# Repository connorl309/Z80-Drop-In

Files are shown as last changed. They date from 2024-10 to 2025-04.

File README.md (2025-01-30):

# Z80-Drop-In
Relevant links and information:
- [Instruction Set](https://map.grauw.nl/resources/z80instr.php)
- [Z80 User Manual](https://www.zilog.com/docs/z80/um0080.pdf)
- [Master Reference Website](http://z80.info/)
- [Timing Quirks](https://floooh.github.io/2021/12/06/z80-instruction-timing.html#extra-clock-cycles)

## Summary
This is the Github repository for the senior design capstone project class at the University of Texas at Austin's ECE program (ECE 364/464). Our group is Industry Honors 01 (IH01), a Drop-in CPU Replacement for the Zilog Z80 processor, comprised of six members:

1. [Connor Leu](https://github.com/connorl309) - Team lead, organizer, maintainer, PCB design
2. [April Douglas](https://github.com/MaprilBear) - ALU RTL, processor design
3. [Gage Miller](https://github.com/millergage) - Register file RTL, processor design
4. [Luke Mason](https://github.com/Mega567835) - Control store, microsequencer, FSM design
5. [Nadia Houston](https://github.com/nadiahouston) - Control store, microsequencer, FSM design
6. [Gabriel Moore](https://github.com/K0-p) - Hardware testing, development boards

This project is considered an industry-honors project; as such, we are sponsored and primarily funded by an industry company, [Phoenix Semiconductor](https://www.phoenixsemicorp.com/).

The premise behind our drop-in replacement is to create a cycle-accurate processor core emulator on an FPGA. For our project, under company guidance, we are targeting the Spartan-7 XC7S15. The emulated processor core will sit on a supporting custom PCB, sized to the original form factor (approx. 17mm x 50mm) of the Zilog Z80. This PCB will then assume the position of a Z80 in any Z80 system, mimicking original processor behavior accurately.

The two major components of this project is the processor design and the hardware design. Our processor emulation core is split into datapath design and a control store/microcode FSM. The three major components of the datapath are the ALU, register file, and control logic. The control store and microcode represent our implementation of the original Z80's PLA for instruction decode and processor operation. Our RTL design decisions have been informed by over 40 years of processor execution behavior, the original user manual, and countless online documents written by reverse engineers and hobbyists. (see [Master Reference Website](http://z80.info/))

The hardware design is also split into two primary components: the devhat translation boards, used to level-shift our development boards 3.3V signals to the Z80 5V level and vice versa, and the System-in-Package board, which is the final goal of the project. The SiP board features the Spartan-7 FPGA, control hardware, QSPI flash memory, and other supporting circuitry in the size of the original Z80 package. Our hope is that this final board will be a true drop-in replacement for Z80 processors.

The SiP board can be found in [hardware/sip-board](hardware/sip-board/), and the level shifter board can be found in [hardware/level-shifter/](hardware/level-shifter/). Component files are kind of messy, but both Kicad Projects should all be using RELATIVE paths for custom symbols and footprints.

## Tools
Given the nature of an FPGA-based processor emulator, we opted to use as many industry-standard tools as possible. Our RTL is written in Verilog under the Vivado Design Suite, targeting a Spartan-7 **XC7S15** FPGA for final project completion. We are hoping to acquire physical testing equipment to validate circuit boards. Our hardware is designed using KiCad, as the University does not provide licenses for software such as Altium or Allegro.

## Building and Testing
Vivado's IP for FPGAs has lots of different blocks we can use. One such IP block is the [integrated logic analyzer (ILA)](https://www.xilinx.com/products/intellectual-property/ila.html). Instead of needing more PCBs or fancy test rigs, we can utilize the ILA directly on our development FPGA boards and dump waveforms right back out to the host PC and into the Vivado Waveform viewer. This is our primary method of testing and verification on the development boards (purchased from Numato - the Narvi S7). In addition to the ILA, our devboards also contain FTDI chips that let us communicate over serial to the host computer.
Our goal for devboard testing is to be able to execute any number of sample programs for the Z80, and verify that all control signals are accurate to both the M- and T-cycle level. This will likely take the form of short sample programs for all instructions, and then combined into larger test programs with more complex behavior whose validity will be examined on a results level, not a cycle level.

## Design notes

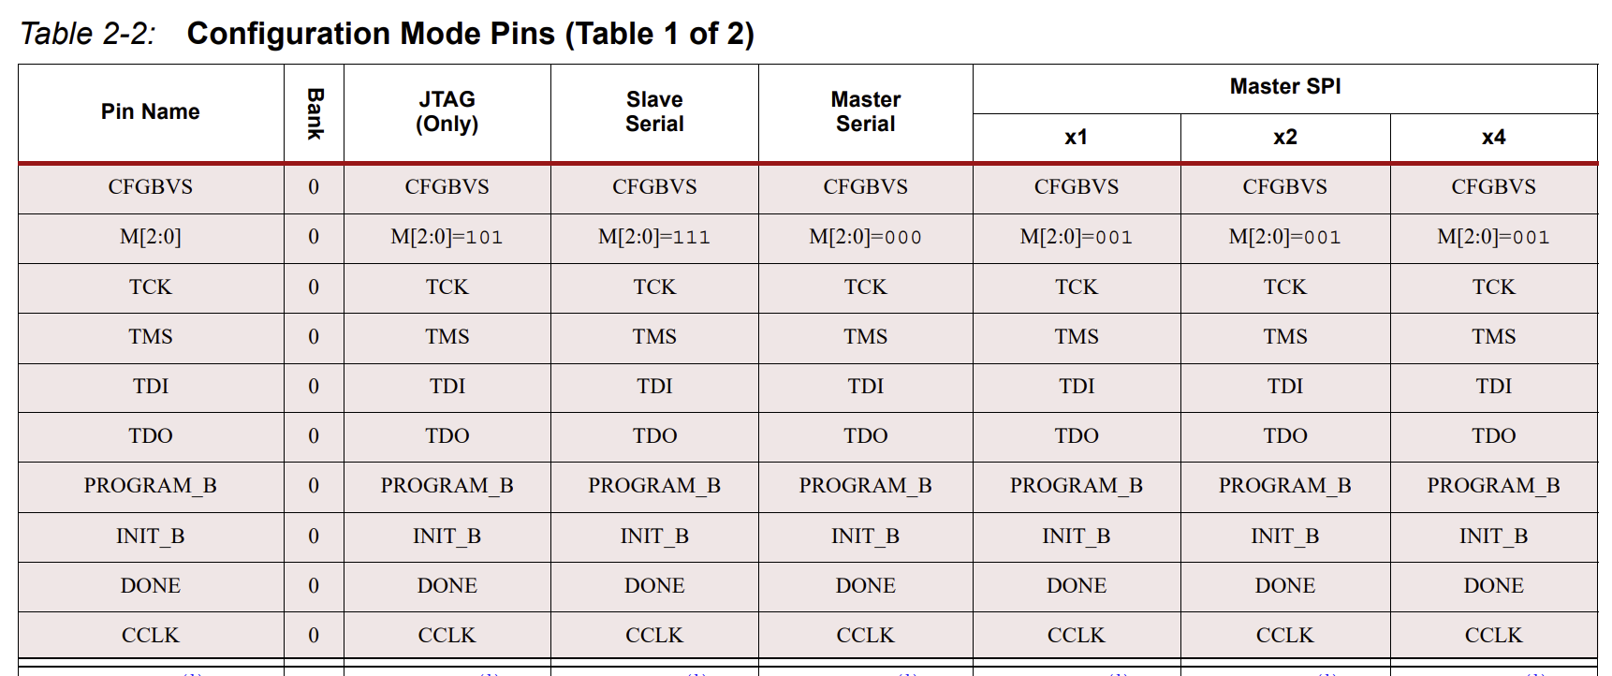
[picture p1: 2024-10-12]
hardware/xc7s15 configuration pin table.png

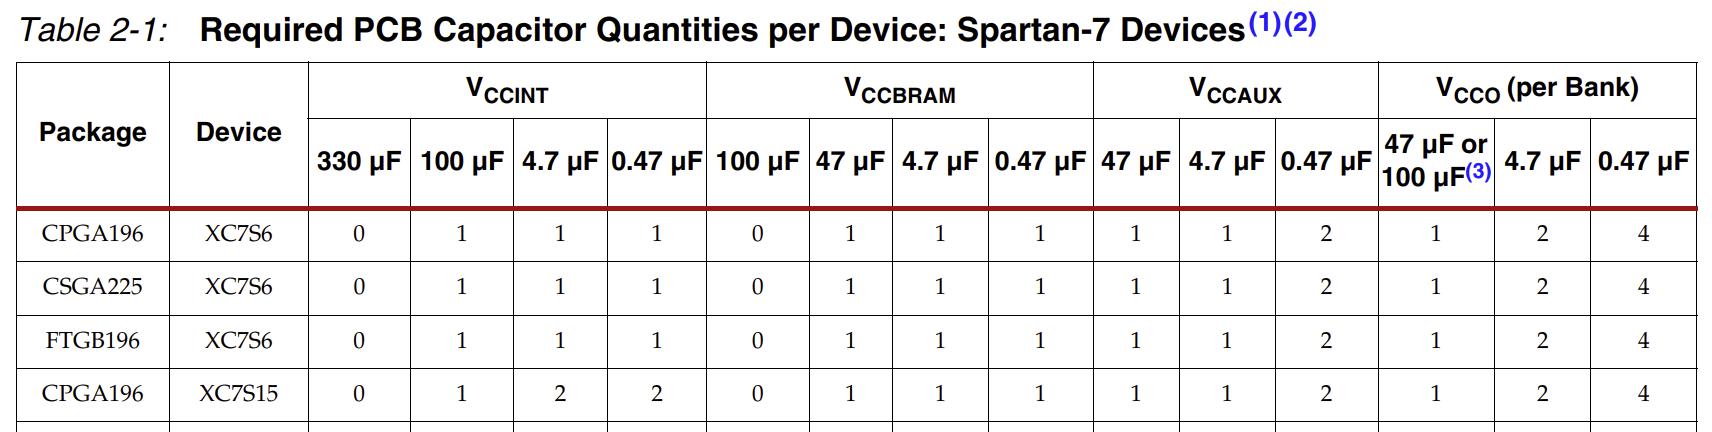
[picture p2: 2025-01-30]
hardware/decoupling caps.png

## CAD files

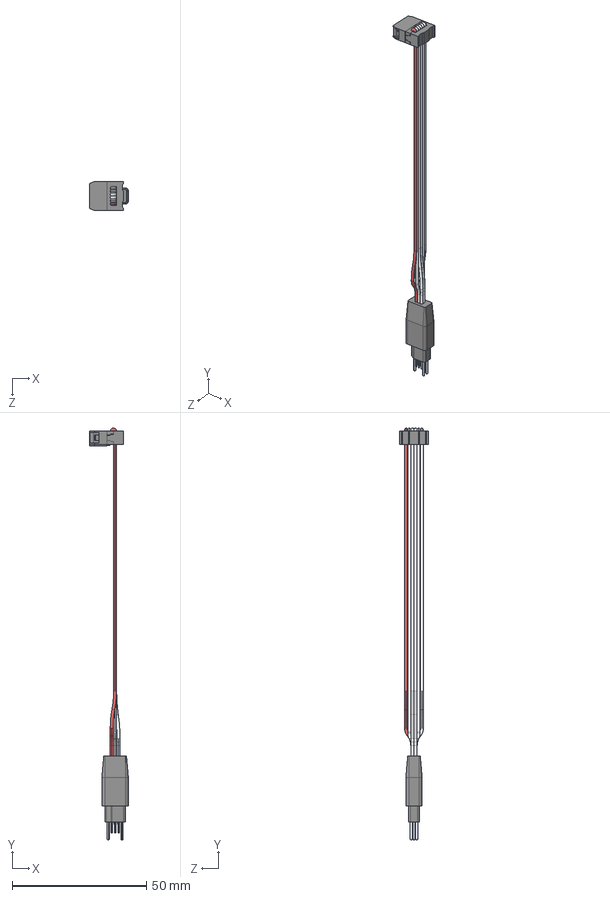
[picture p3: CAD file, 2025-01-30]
hardware/TC2030-IDC-NL.step
14.5 x 153.6 x 10.7 mm

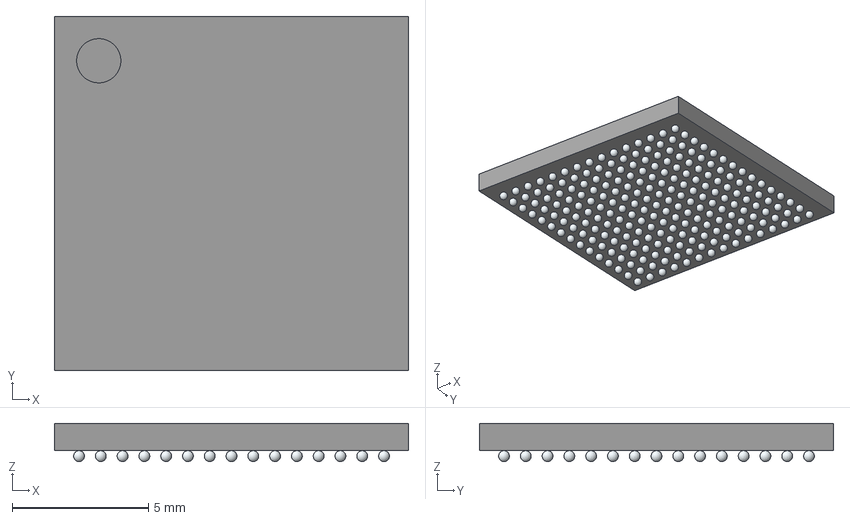
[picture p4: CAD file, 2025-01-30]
hardware/XC7S25-2CSGA225I.stp
13.0 x 13.0 x 1.40 mm

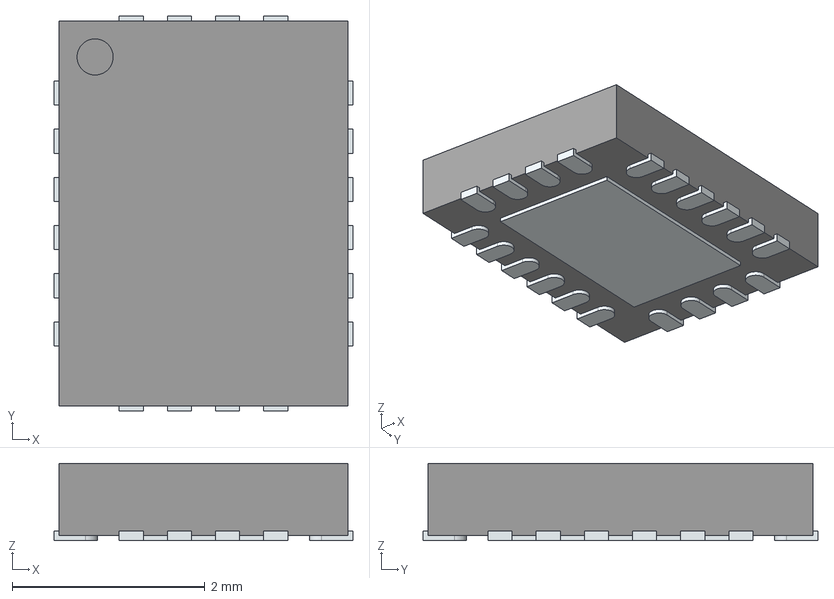
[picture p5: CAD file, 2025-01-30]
hardware/LTC3569EUDC#TRPBF.stp
3.10 x 4.10 x 0.8 mm
ThermalPin
PinsArrayLR
PinsArrayTB

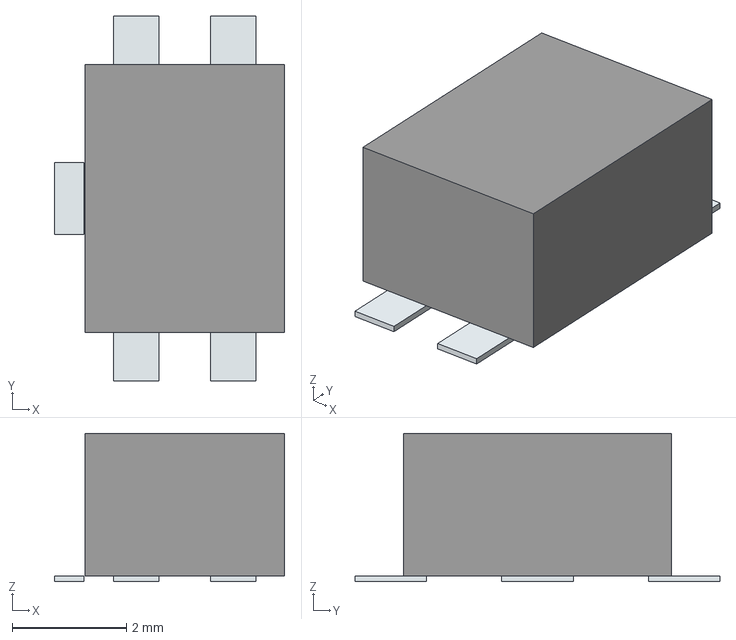
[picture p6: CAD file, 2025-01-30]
hardware/EVQ-P2R02W.stp
4.04 x 6.40 x 2.60 mm
Pins

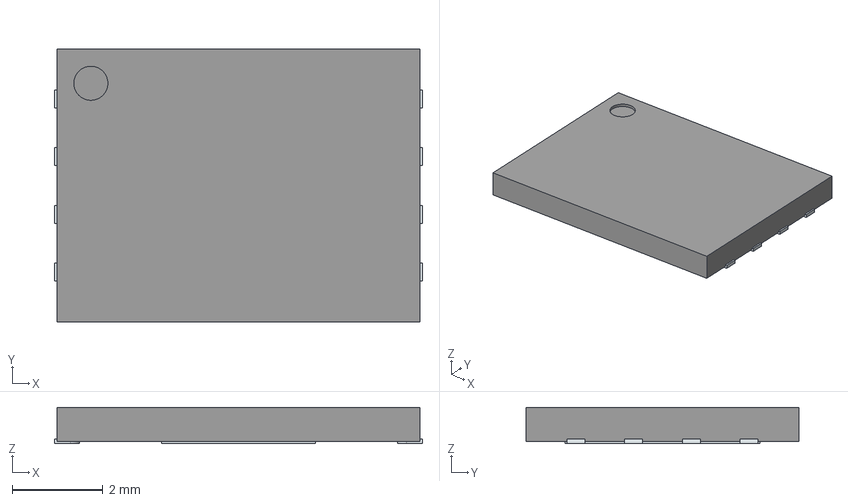
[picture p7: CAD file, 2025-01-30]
hardware/MT25QL512ABB1EW9-0SIT.stp
8.10 x 6.00 x 0.8 mm
ThermalPin
PinsArrayLR

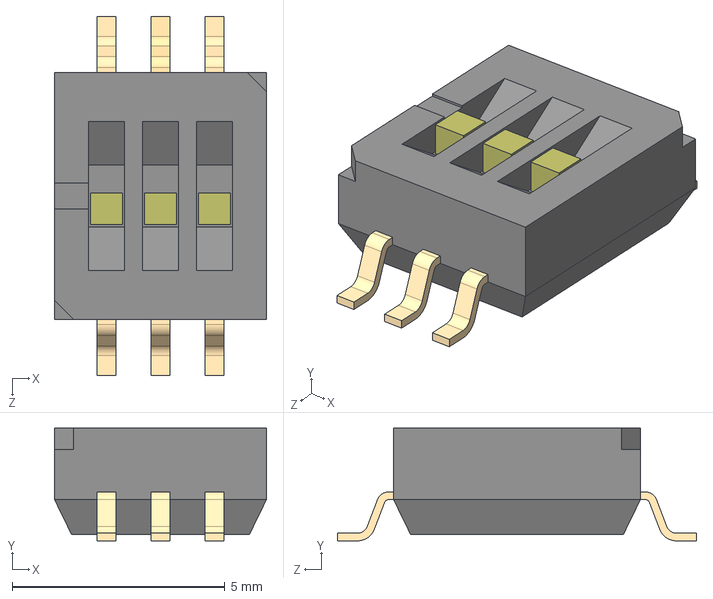
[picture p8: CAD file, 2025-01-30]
hardware/416131160803.stp
4.98 x 2.65 x 8.44 mm

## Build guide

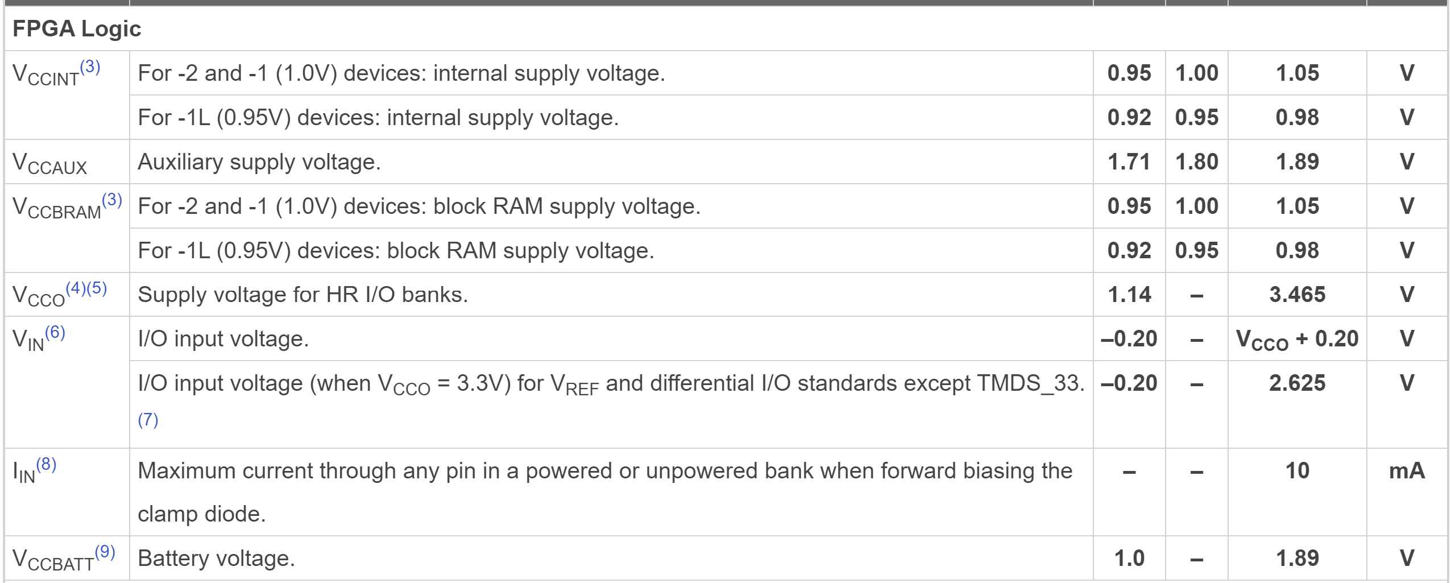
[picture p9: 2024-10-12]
hardware/xc7s15 operating power conditions.png

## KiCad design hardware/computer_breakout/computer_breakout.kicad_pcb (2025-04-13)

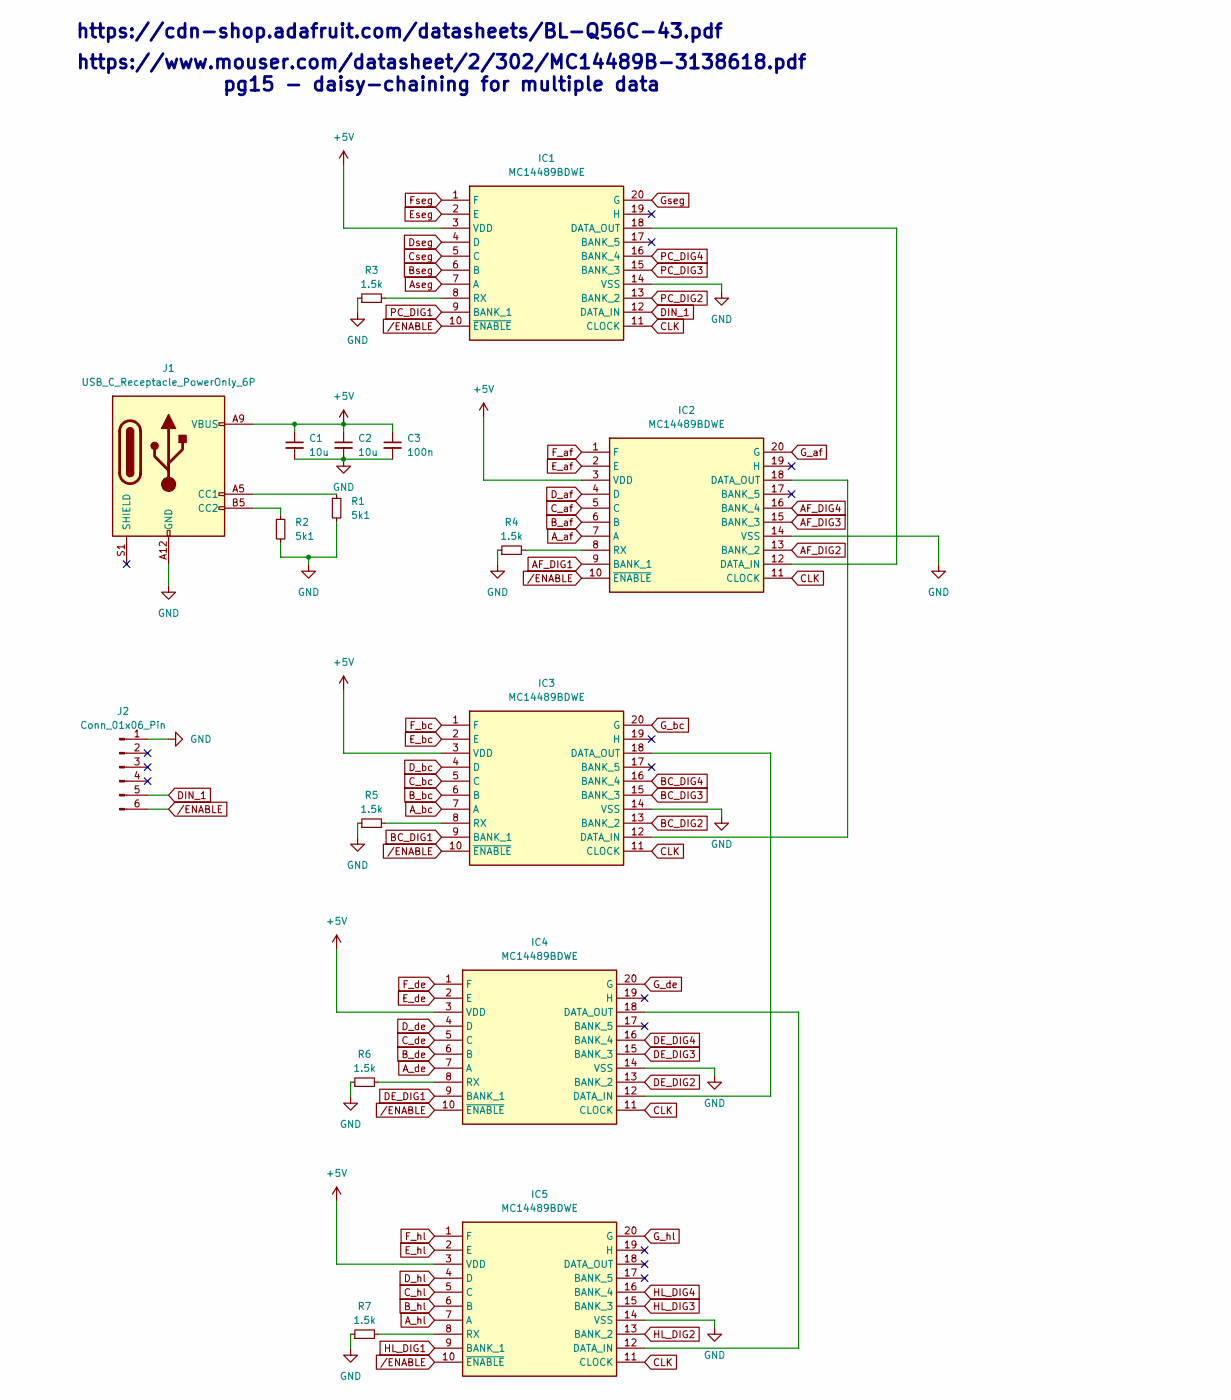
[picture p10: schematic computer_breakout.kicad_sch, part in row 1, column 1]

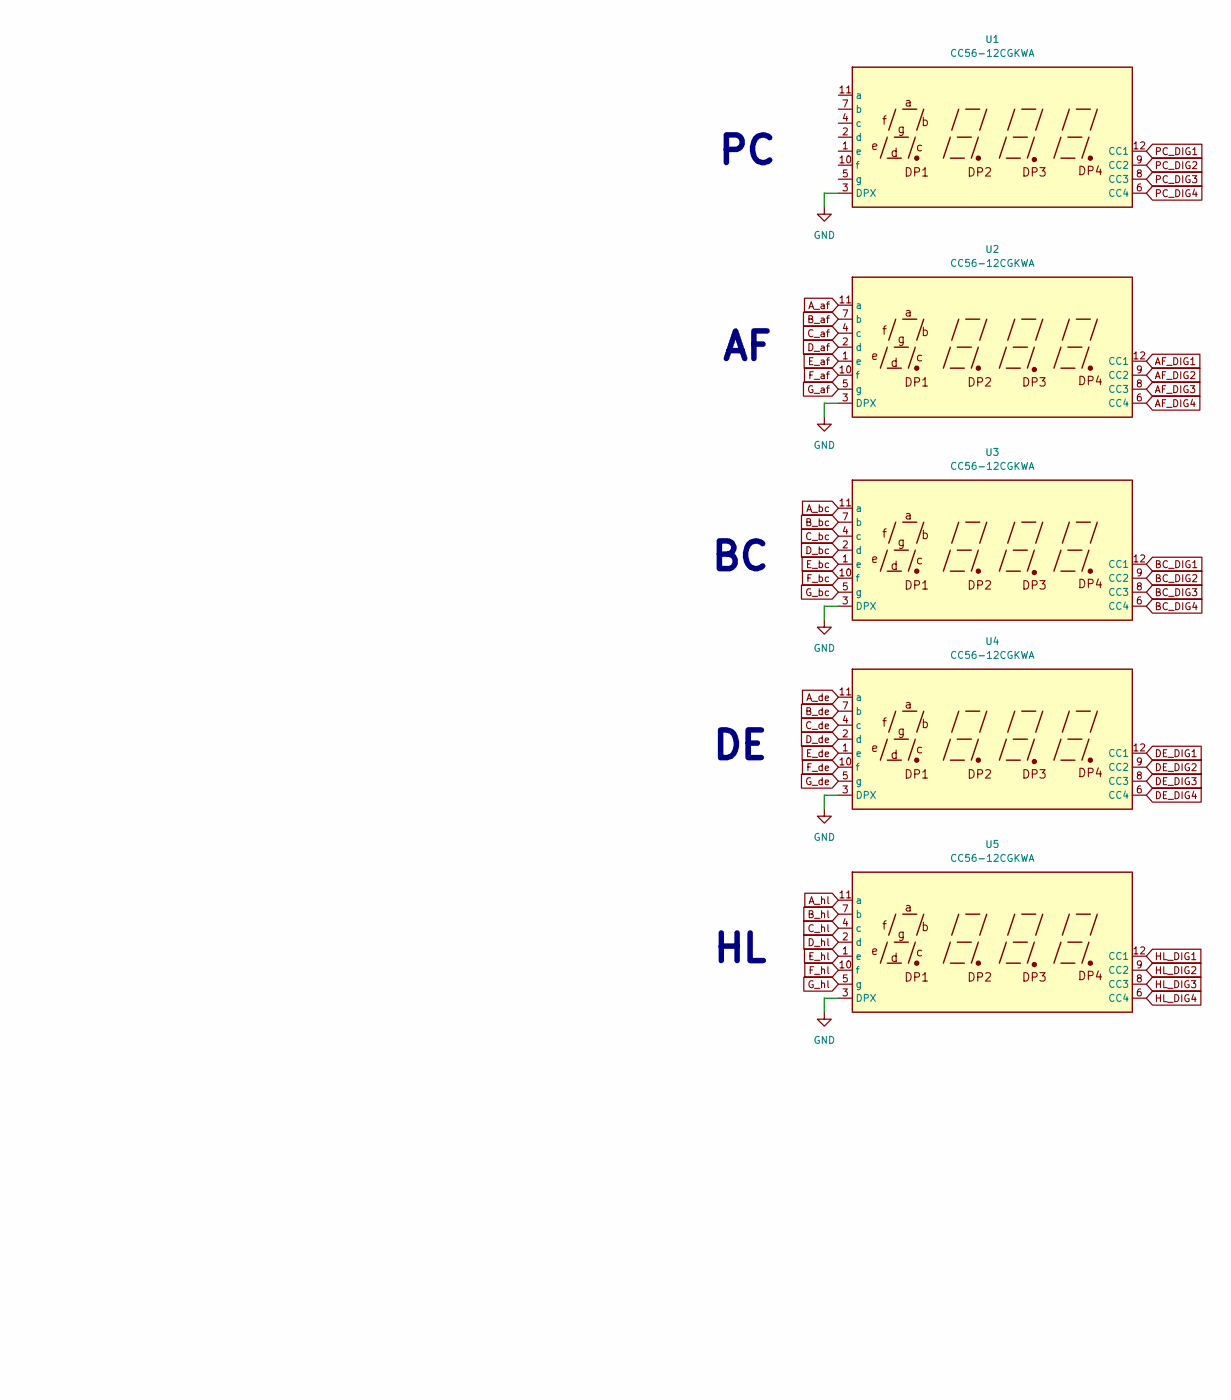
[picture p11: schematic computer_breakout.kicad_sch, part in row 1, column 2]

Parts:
C1, C2: 10u; C_1206_3216Metric_Pad1.33x1.80mm_HandSolder
C3: 100n; C_0603_1608Metric_Pad1.08x0.95mm_HandSolder
IC1, IC2, IC3, IC4, IC5: MC14489BDWE; SOIC127P1030X265-20N; Mouser Part Number 841-MC14489BDWE
J1: USB_C_Receptacle_PowerOnly_6P; USB_C_Receptacle_GCT_USB4110
J2: Conn_01x06_Pin; PinHeader_1x06_P2.54mm_Vertical
R1, R2: 5k1; R_1812_4532Metric_Pad1.30x3.40mm_HandSolder
R3, R4, R5, R6, R7: 1.5k; R_1812_4532Metric_Pad1.30x3.40mm_HandSolder
U1, U2, U3, U4, U5: CC56-12CGKWA; CA56-12CGKWA

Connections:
+5V: C1.1, C2.1, C3.1, IC1.3 (VDD), IC2.3 (VDD), IC3.3 (VDD), IC4.3 (VDD), IC5.3 (VDD), J1.A9 (VBUS), J1.B9 (VBUS)
AF_DIG1: IC2.9 (BANK_1), U2.12 (CC1)
AF_DIG2: IC2.13 (BANK_2), U2.9 (CC2)
AF_DIG3: IC2.15 (BANK_3), U2.8 (CC3)
AF_DIG4: IC2.16 (BANK_4), U2.6 (CC4)
A_af: IC2.7 (A), U2.11 (a)
A_bc: IC3.7 (A), U3.11 (a)
A_de: IC4.7 (A), U4.11 (a)
A_hl: IC5.7 (A), U5.11 (a)
Aseg: IC1.7 (A)
BC_DIG1: IC3.9 (BANK_1), U3.12 (CC1)
BC_DIG2: IC3.13 (BANK_2), U3.9 (CC2)
BC_DIG3: IC3.15 (BANK_3), U3.8 (CC3)
BC_DIG4: IC3.16 (BANK_4), U3.6 (CC4)
B_af: IC2.6 (B), U2.7 (b)
B_bc: IC3.6 (B), U3.7 (b)
B_de: IC4.6 (B), U4.7 (b)
B_hl: IC5.6 (B), U5.7 (b)
Bseg: IC1.6 (B)
CLK: IC1.11 (CLOCK), IC2.11 (CLOCK), IC3.11 (CLOCK), IC4.11 (CLOCK), IC5.11 (CLOCK)
C_af: IC2.5 (C), U2.4 (c)
C_bc: IC3.5 (C), U3.4 (c)
C_de: IC4.5 (C), U4.4 (c)
C_hl: IC5.5 (C), U5.4 (c)
Cseg: IC1.5 (C)
DE_DIG1: IC4.9 (BANK_1), U4.12 (CC1)
DE_DIG2: IC4.13 (BANK_2), U4.9 (CC2)
DE_DIG3: IC4.15 (BANK_3), U4.8 (CC3)
DE_DIG4: IC4.16 (BANK_4), U4.6 (CC4)
DIN_1: IC1.12 (DATA_IN), J2.5
D_af: IC2.4 (D), U2.2 (d)
D_bc: IC3.4 (D), U3.2 (d)
D_de: IC4.4 (D), U4.2 (d)
D_hl: IC5.4 (D), U5.2 (d)
Dseg: IC1.4 (D)
E_af: IC2.2 (E), U2.1 (e)
E_bc: IC3.2 (E), U3.1 (e)
E_de: IC4.2 (E), U4.1 (e)
E_hl: IC5.2 (E), U5.1 (e)
Eseg: IC1.2 (E)
F_af: IC2.1 (F), U2.10 (f)
F_bc: IC3.1 (F), U3.10 (f)
F_de: IC4.1 (F), U4.10 (f)
F_hl: IC5.1 (F), U5.10 (f)
Fseg: IC1.1 (F)
GND: C1.2, C2.2, C3.2, IC1.14 (VSS), IC2.14 (VSS), IC3.14 (VSS), IC4.14 (VSS), IC5.14 (VSS), J1.A12 (GND), J1.B12 (GND), J2.1, R1.2, R2.2, R3.1, R4.1, R5.1, R6.1, R7.1, U1.3 (DPX), U2.3 (DPX), U3.3 (DPX), U4.3 (DPX), U5.3 (DPX)
G_af: IC2.20 (G), U2.5 (g)
G_bc: IC3.20 (G), U3.5 (g)
G_de: IC4.20 (G), U4.5 (g)
G_hl: IC5.20 (G), U5.5 (g)
Gseg: IC1.20 (G)
HL_DIG1: IC5.9 (BANK_1), U5.12 (CC1)
HL_DIG2: IC5.13 (BANK_2), U5.9 (CC2)
HL_DIG3: IC5.15 (BANK_3), U5.8 (CC3)
HL_DIG4: IC5.16 (BANK_4), U5.6 (CC4)
unnamed: IC1.18 (DATA_OUT), IC2.12 (DATA_IN)
unnamed: IC1.8 (RX), R3.2
unnamed: IC2.18 (DATA_OUT), IC3.12 (DATA_IN)
unnamed: IC2.8 (RX), R4.2
unnamed: IC3.18 (DATA_OUT), IC4.12 (DATA_IN)
unnamed: IC3.8 (RX), R5.2
unnamed: IC4.18 (DATA_OUT), IC5.12 (DATA_IN)
unnamed: IC4.8 (RX), R6.2
unnamed: IC5.8 (RX), R7.2
unnamed: J1.A5 (CC1), R1.1
unnamed: J1.B5 (CC2), R2.1
PC_DIG1: IC1.9 (BANK_1), U1.12 (CC1)
PC_DIG2: IC1.13 (BANK_2), U1.9 (CC2)
PC_DIG3: IC1.15 (BANK_3), U1.8 (CC3)
PC_DIG4: IC1.16 (BANK_4), U1.6 (CC4)
/ENABLE: IC1.10 (~ENABLE), IC2.10 (~ENABLE), IC3.10 (~ENABLE), IC4.10 (~ENABLE), IC5.10 (~ENABLE), J2.6

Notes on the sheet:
https://www.mouser.com/datasheet/2/302/MC14489B-3138618.pdf pg15 - daisy-chaining for multiple data
https://cdn-shop.adafruit.com/datasheets/BL-Q56C-43.pdf

Board: 2 copper layers, 22 parts (0 on the bottom side), 64 nets, no tracks yet.

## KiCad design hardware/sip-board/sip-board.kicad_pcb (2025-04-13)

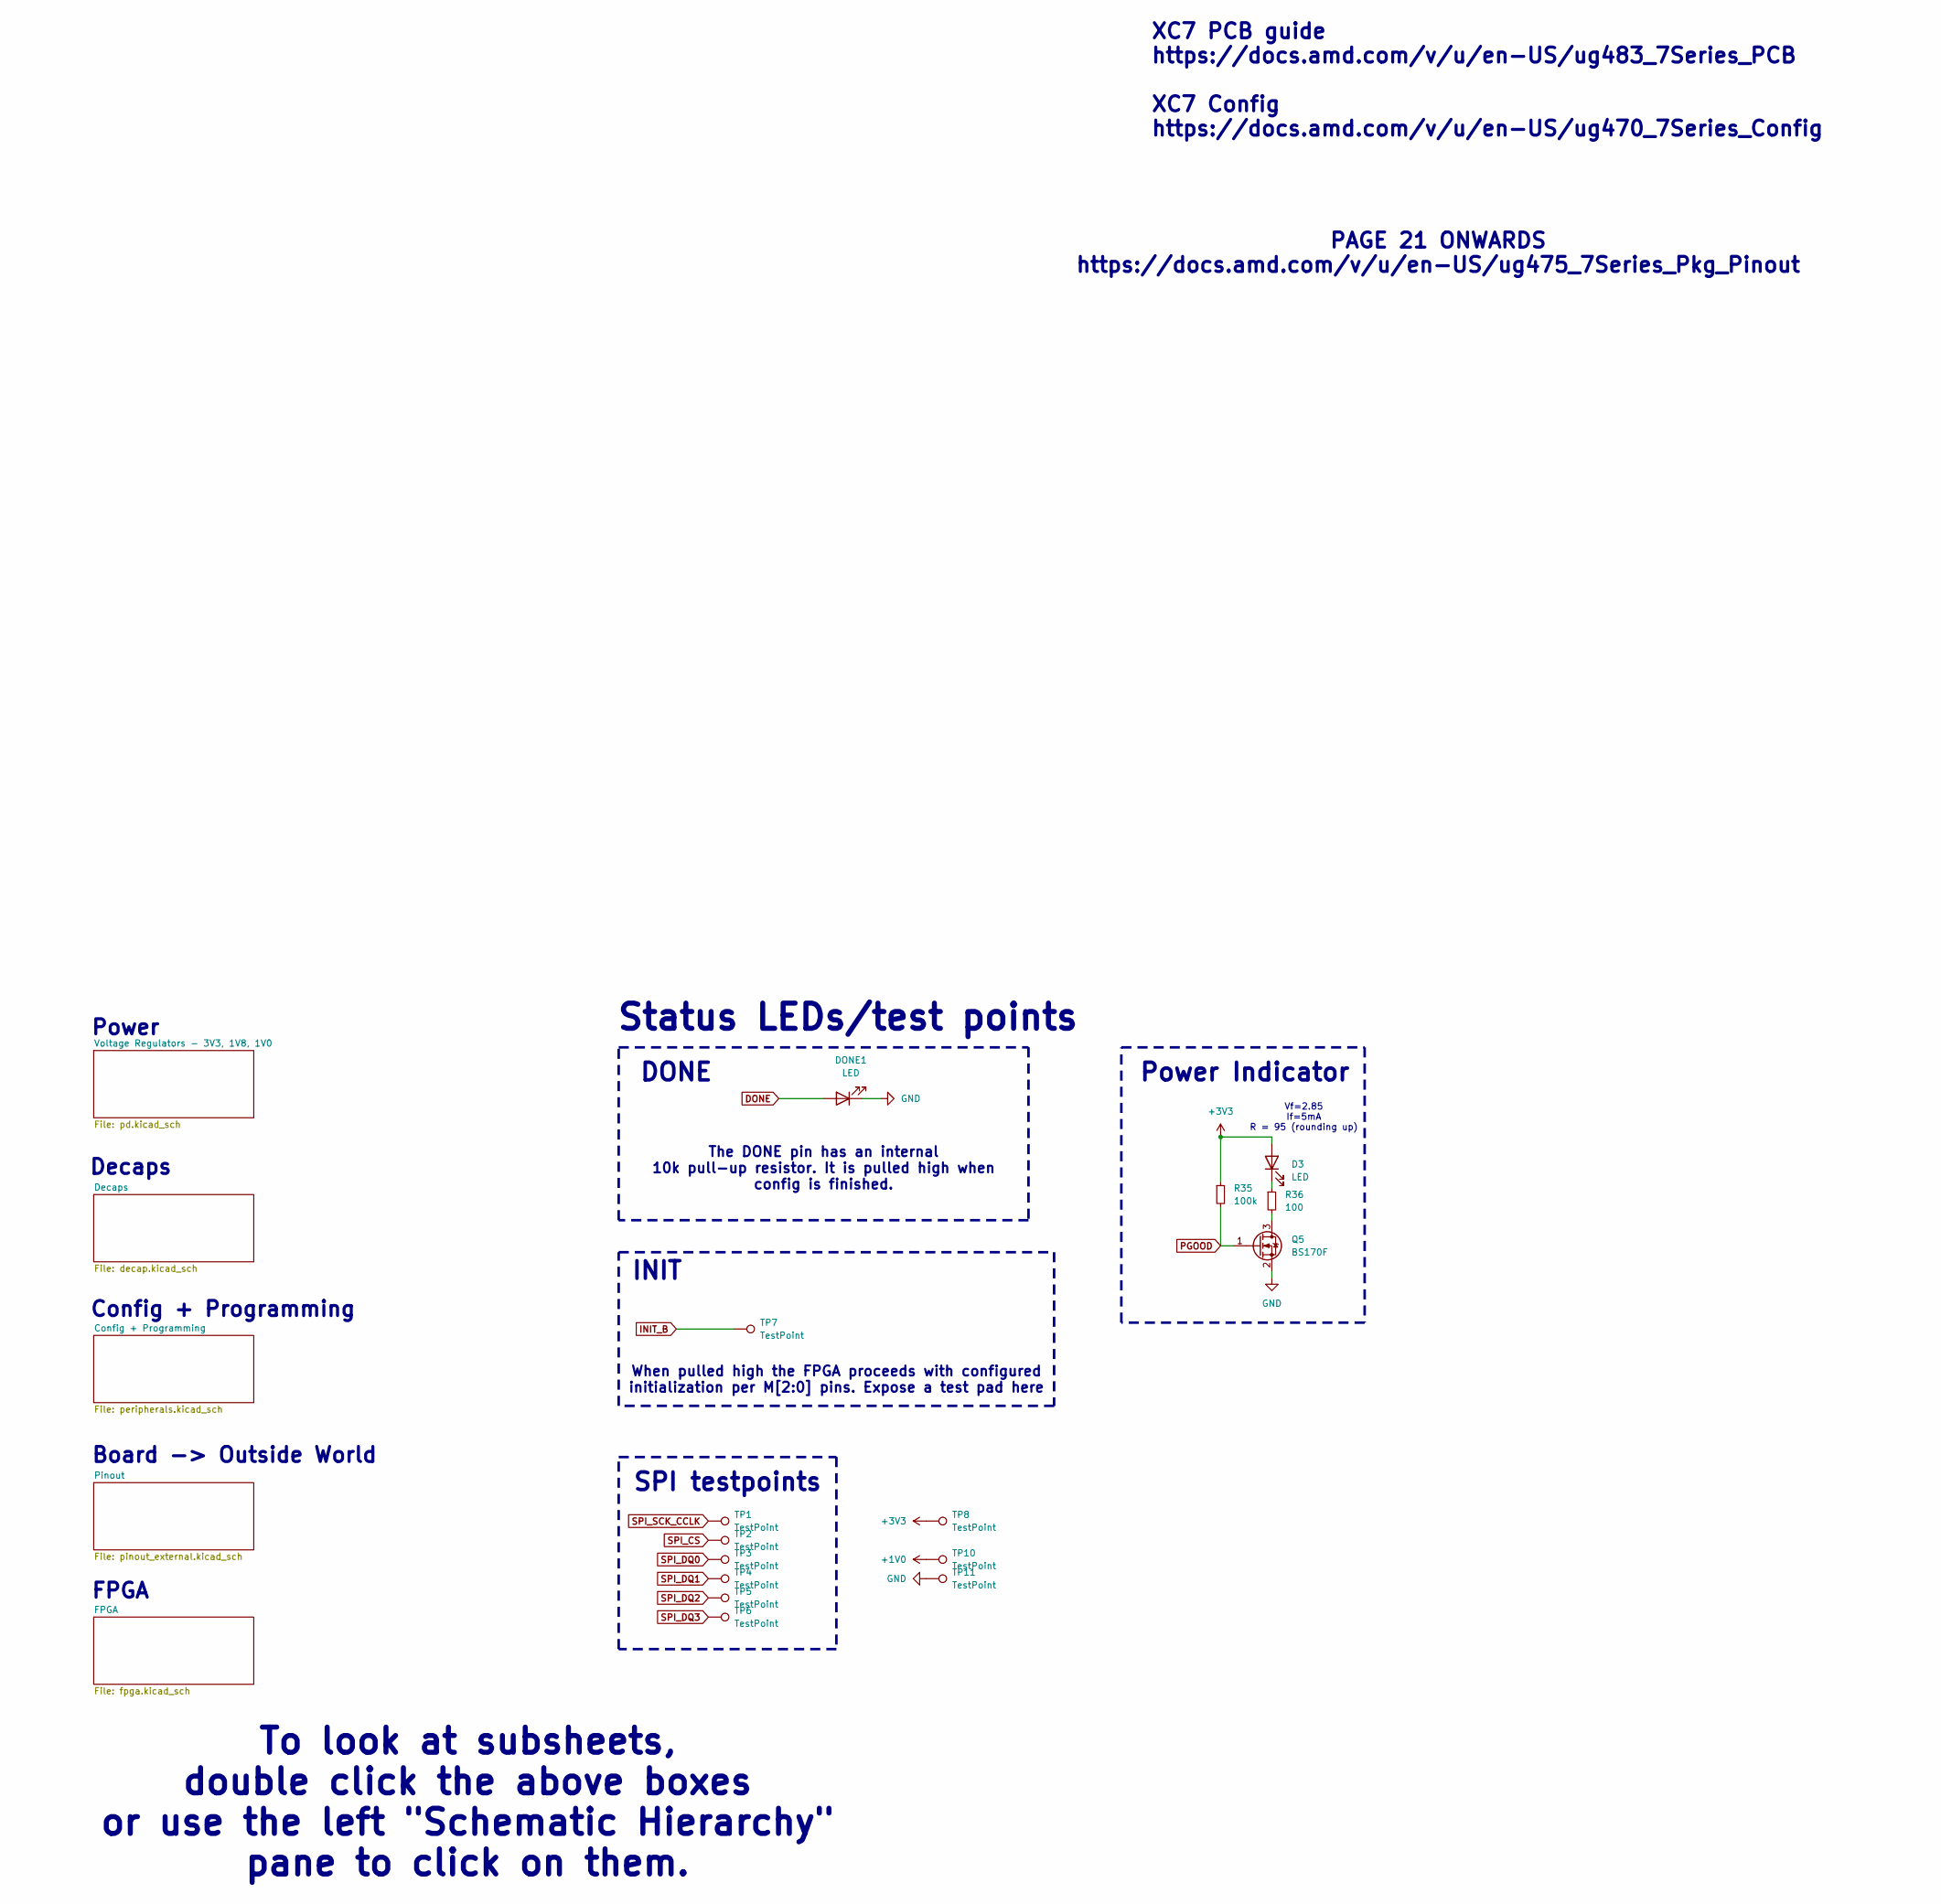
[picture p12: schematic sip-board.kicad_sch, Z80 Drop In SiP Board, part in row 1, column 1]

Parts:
D3: LED; LED_0402_1005Metric
DONE1: LED; LED_0402_1005Metric
Q5: BS170F; SOT-23
R35: 100k; R_0201_0603Metric
R36: 100; R_0201_0603Metric
TP1, TP2, TP3, TP4, TP5, TP6, TP7, TP8, TP10, TP11: TestPoint; TestPoint_Pad_1.0x1.0mm

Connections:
+1V0: TP10.1; also elsewhere on the board
+3V3: D3.2 (A), R35.1, TP8.1; also elsewhere on the board
DONE: DONE1.2 (A); also elsewhere on the board
GND: DONE1.1 (K), Q5.2 (S), TP11.1; also elsewhere on the board
INIT_B: TP7.1; also elsewhere on the board
unnamed: D3.1 (K), R36.1
unnamed: Q5.3 (D), R36.2
PGOOD: Q5.1 (G), R35.2; also elsewhere on the board
SPI_CS: TP2.1; also elsewhere on the board
SPI_DQ0: TP3.1; also elsewhere on the board
SPI_DQ1: TP4.1; also elsewhere on the board
SPI_DQ2: TP5.1; also elsewhere on the board
SPI_DQ3: TP6.1; also elsewhere on the board
SPI_SCK_CCLK: TP1.1; also elsewhere on the board

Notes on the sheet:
Power
Status LEDs/test points
FPGA
Decaps
XC7 PCB guide https://docs.amd.com/v/u/en-US/ug483_7Series_PCB XC7 Config https://docs.amd.com/v/u/en-US/ug470_7Series_Config
Board -> Outside World
Power Indicator
PAGE 21 ONWARDS https://docs.amd.com/v/u/en-US/ug475_7Series_Pkg_Pinout
INIT
Config + Programming
https://docs.amd.com/r/en-US/ug1099-bga-device-design-rules/Power-Delivery-to-the-FPGA
When pulled high the FPGA proceeds with configured initialization per M[2:0] pins. Expose a test pad here
DONE
The DONE pin has an internal 10k pull-up resistor. It is pulled high when config is finished.
SPI testpoints
To look at subsheets, double click the above boxes or use the left "Schematic Hierarchy" pane to click on them.
Vf=2.85 If=5mA R = 95 (rounding up)

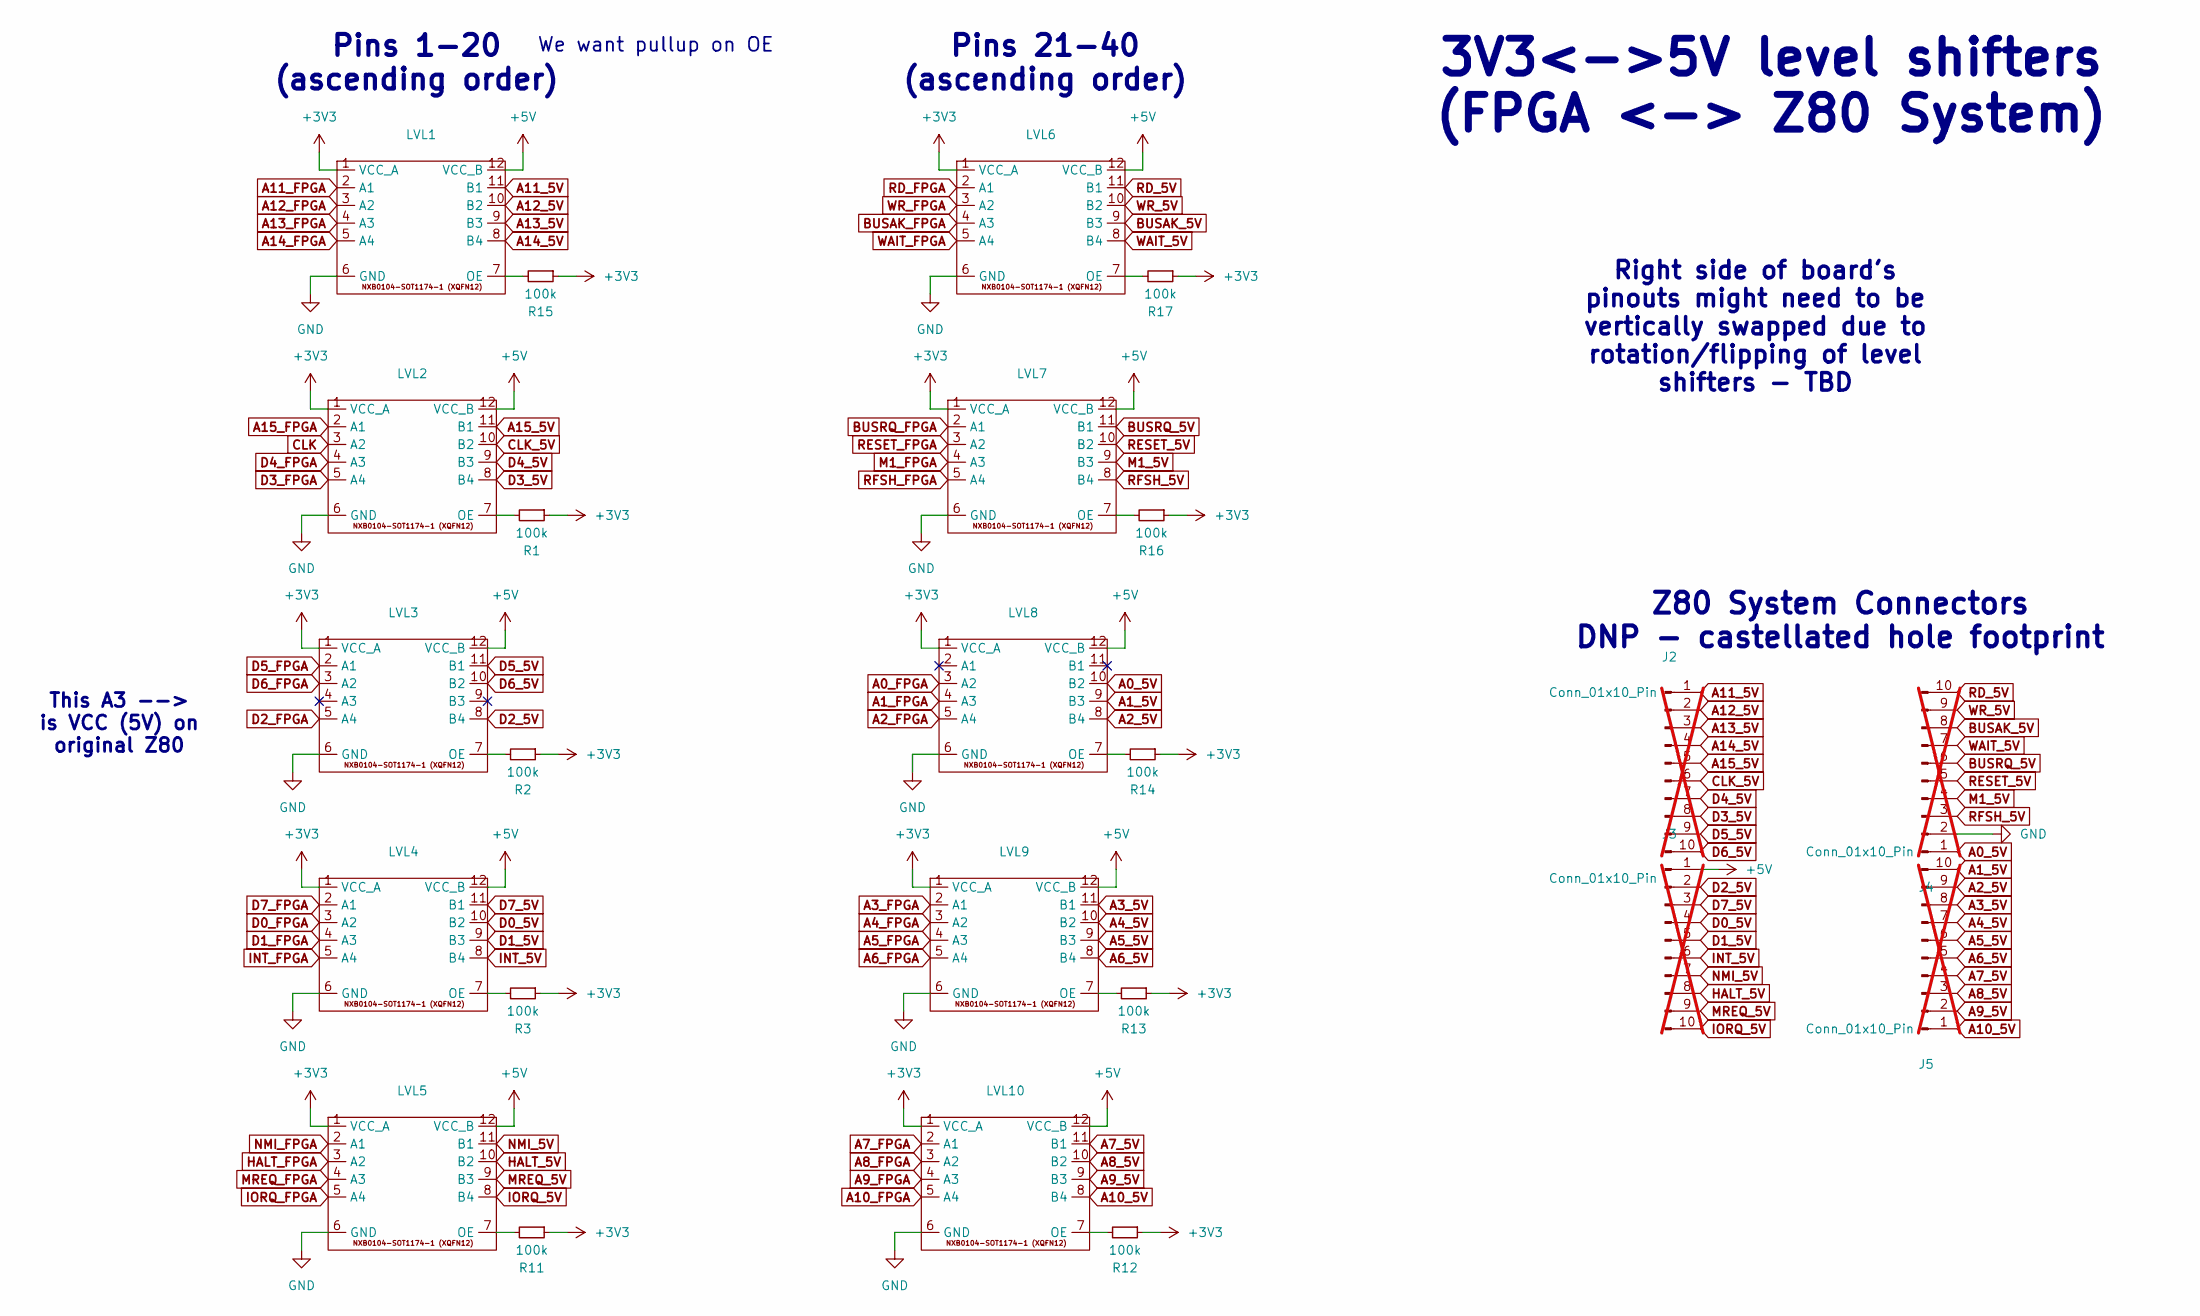
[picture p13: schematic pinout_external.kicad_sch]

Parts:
J2, J3, J4, J5: Conn_01x10_Pin; PinHeader_1x10_P2.54mm_Vertical; not fitted
LVL1, LVL2, LVL3, LVL4, LVL5, LVL6, LVL7, LVL8, LVL9, LVL10: NXB0104GU12X; MPN NXB0104GU12X
R1, R2, R3, R11, R12, R13, R14, R15, R16, R17: 100k; R_0201_0603Metric

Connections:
+3V3: LVL1.1 (VCC_A), LVL2.1 (VCC_A), LVL3.1 (VCC_A), LVL4.1 (VCC_A), LVL5.1 (VCC_A), LVL6.1 (VCC_A), LVL7.1 (VCC_A), LVL8.1 (VCC_A), LVL9.1 (VCC_A), LVL10.1 (VCC_A), R1.1, R2.1, R3.1, R11.1, R12.1, R13.1, R14.1, R15.1, R16.1, R17.1; also elsewhere on the board
+5V: J3.1, LVL1.12 (VCC_B), LVL2.12 (VCC_B), LVL3.12 (VCC_B), LVL4.12 (VCC_B), LVL5.12 (VCC_B), LVL6.12 (VCC_B), LVL7.12 (VCC_B), LVL8.12 (VCC_B), LVL9.12 (VCC_B), LVL10.12 (VCC_B); also elsewhere on the board
A0_5V: J4.1, LVL8.10 (B2)
A0_FPGA: LVL8.3 (A2); also elsewhere on the board
A1_5V: J5.10, LVL8.9 (B3)
A1_FPGA: LVL8.4 (A3); also elsewhere on the board
A2_5V: J5.9, LVL8.8 (B4)
A2_FPGA: LVL8.5 (A4); also elsewhere on the board
A3_5V: J5.8, LVL9.11 (B1)
A3_FPGA: LVL9.2 (A1); also elsewhere on the board
A4_5V: J5.7, LVL9.10 (B2)
A4_FPGA: LVL9.3 (A2); also elsewhere on the board
A5_5V: J5.6, LVL9.9 (B3)
A5_FPGA: LVL9.4 (A3); also elsewhere on the board
A6_5V: J5.5, LVL9.8 (B4)
A6_FPGA: LVL9.5 (A4); also elsewhere on the board
A7_5V: J5.4, LVL10.11 (B1)
A7_FPGA: LVL10.2 (A1); also elsewhere on the board
A8_5V: J5.3, LVL10.10 (B2)
A8_FPGA: LVL10.3 (A2); also elsewhere on the board
A9_5V: J5.2, LVL10.9 (B3)
A9_FPGA: LVL10.4 (A3); also elsewhere on the board
A10_5V: J5.1, LVL10.8 (B4)
A10_FPGA: LVL10.5 (A4); also elsewhere on the board
A11_5V: J2.1, LVL1.11 (B1)
A11_FPGA: LVL1.2 (A1); also elsewhere on the board
A12_5V: J2.2, LVL1.10 (B2)
A12_FPGA: LVL1.3 (A2); also elsewhere on the board
A13_5V: J2.3, LVL1.9 (B3)
A13_FPGA: LVL1.4 (A3); also elsewhere on the board
A14_5V: J2.4, LVL1.8 (B4)
A14_FPGA: LVL1.5 (A4); also elsewhere on the board
A15_5V: J2.5, LVL2.11 (B1)
A15_FPGA: LVL2.2 (A1); also elsewhere on the board
BUSAK_5V: J4.8, LVL6.9 (B3)
BUSAK_FPGA: LVL6.4 (A3); also elsewhere on the board
BUSRQ_5V: J4.6, LVL7.11 (B1)
BUSRQ_FPGA: LVL7.2 (A1); also elsewhere on the board
CLK: LVL2.3 (A2); also elsewhere on the board
CLK_5V: J2.6, LVL2.10 (B2)
D0_5V: J3.4, LVL4.10 (B2)
D0_FPGA: LVL4.3 (A2); also elsewhere on the board
D1_5V: J3.5, LVL4.9 (B3)
D1_FPGA: LVL4.4 (A3); also elsewhere on the board
D2_5V: J3.2, LVL3.8 (B4)
D2_FPGA: LVL3.5 (A4); also elsewhere on the board
D3_5V: J2.8, LVL2.8 (B4)
D3_FPGA: LVL2.5 (A4); also elsewhere on the board
D4_5V: J2.7, LVL2.9 (B3)
D4_FPGA: LVL2.4 (A3); also elsewhere on the board
D5_5V: J2.9, LVL3.11 (B1)
D5_FPGA: LVL3.2 (A1); also elsewhere on the board
D6_5V: J2.10, LVL3.10 (B2)
D6_FPGA: LVL3.3 (A2); also elsewhere on the board
D7_5V: J3.3, LVL4.11 (B1)
D7_FPGA: LVL4.2 (A1); also elsewhere on the board
GND: J4.2, LVL1.6 (GND), LVL2.6 (GND), LVL3.6 (GND), LVL4.6 (GND), LVL5.6 (GND), LVL6.6 (GND), LVL7.6 (GND), LVL8.6 (GND), LVL9.6 (GND), LVL10.6 (GND); also elsewhere on the board
HALT_5V: J3.8, LVL5.10 (B2)
HALT_FPGA: LVL5.3 (A2); also elsewhere on the board
INT_5V: J3.6, LVL4.8 (B4)
INT_FPGA: LVL4.5 (A4); also elsewhere on the board
IORQ_5V: J3.10, LVL5.8 (B4)
IORQ_FPGA: LVL5.5 (A4); also elsewhere on the board
M1_5V: J4.4, LVL7.9 (B3)
M1_FPGA: LVL7.4 (A3); also elsewhere on the board
MREQ_5V: J3.9, LVL5.9 (B3)
MREQ_FPGA: LVL5.4 (A3); also elsewhere on the board
NMI_5V: J3.7, LVL5.11 (B1)
NMI_FPGA: LVL5.2 (A1); also elsewhere on the board
unnamed: LVL1.7 (OE), R15.2
unnamed: LVL2.7 (OE), R1.2
unnamed: LVL3.7 (OE), R2.2
unnamed: LVL4.7 (OE), R3.2
unnamed: LVL5.7 (OE), R11.2
unnamed: LVL6.7 (OE), R17.2
unnamed: LVL7.7 (OE), R16.2
unnamed: LVL8.7 (OE), R14.2
unnamed: LVL9.7 (OE), R13.2
unnamed: LVL10.7 (OE), R12.2
RD_5V: J4.10, LVL6.11 (B1)
RD_FPGA: LVL6.2 (A1); also elsewhere on the board
RESET_5V: J4.5, LVL7.10 (B2)
RESET_FPGA: LVL7.3 (A2); also elsewhere on the board
RFSH_5V: J4.3, LVL7.8 (B4)
RFSH_FPGA: LVL7.5 (A4); also elsewhere on the board
WAIT_5V: J4.7, LVL6.8 (B4)
WAIT_FPGA: LVL6.5 (A4); also elsewhere on the board
WR_5V: J4.9, LVL6.10 (B2)
WR_FPGA: LVL6.3 (A2); also elsewhere on the board

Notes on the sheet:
3V3<->5V level shifters (FPGA <-> Z80 System)
Z80 System Connectors DNP - castellated hole footprint
This A3 --> is VCC (5V) on original Z80
We want pullup on OE
Right side of board's pinouts might need to be vertically swapped due to rotation/flipping of level shifters - TBD
Pins 21-40 (ascending order)
Pins 1-20 (ascending order)

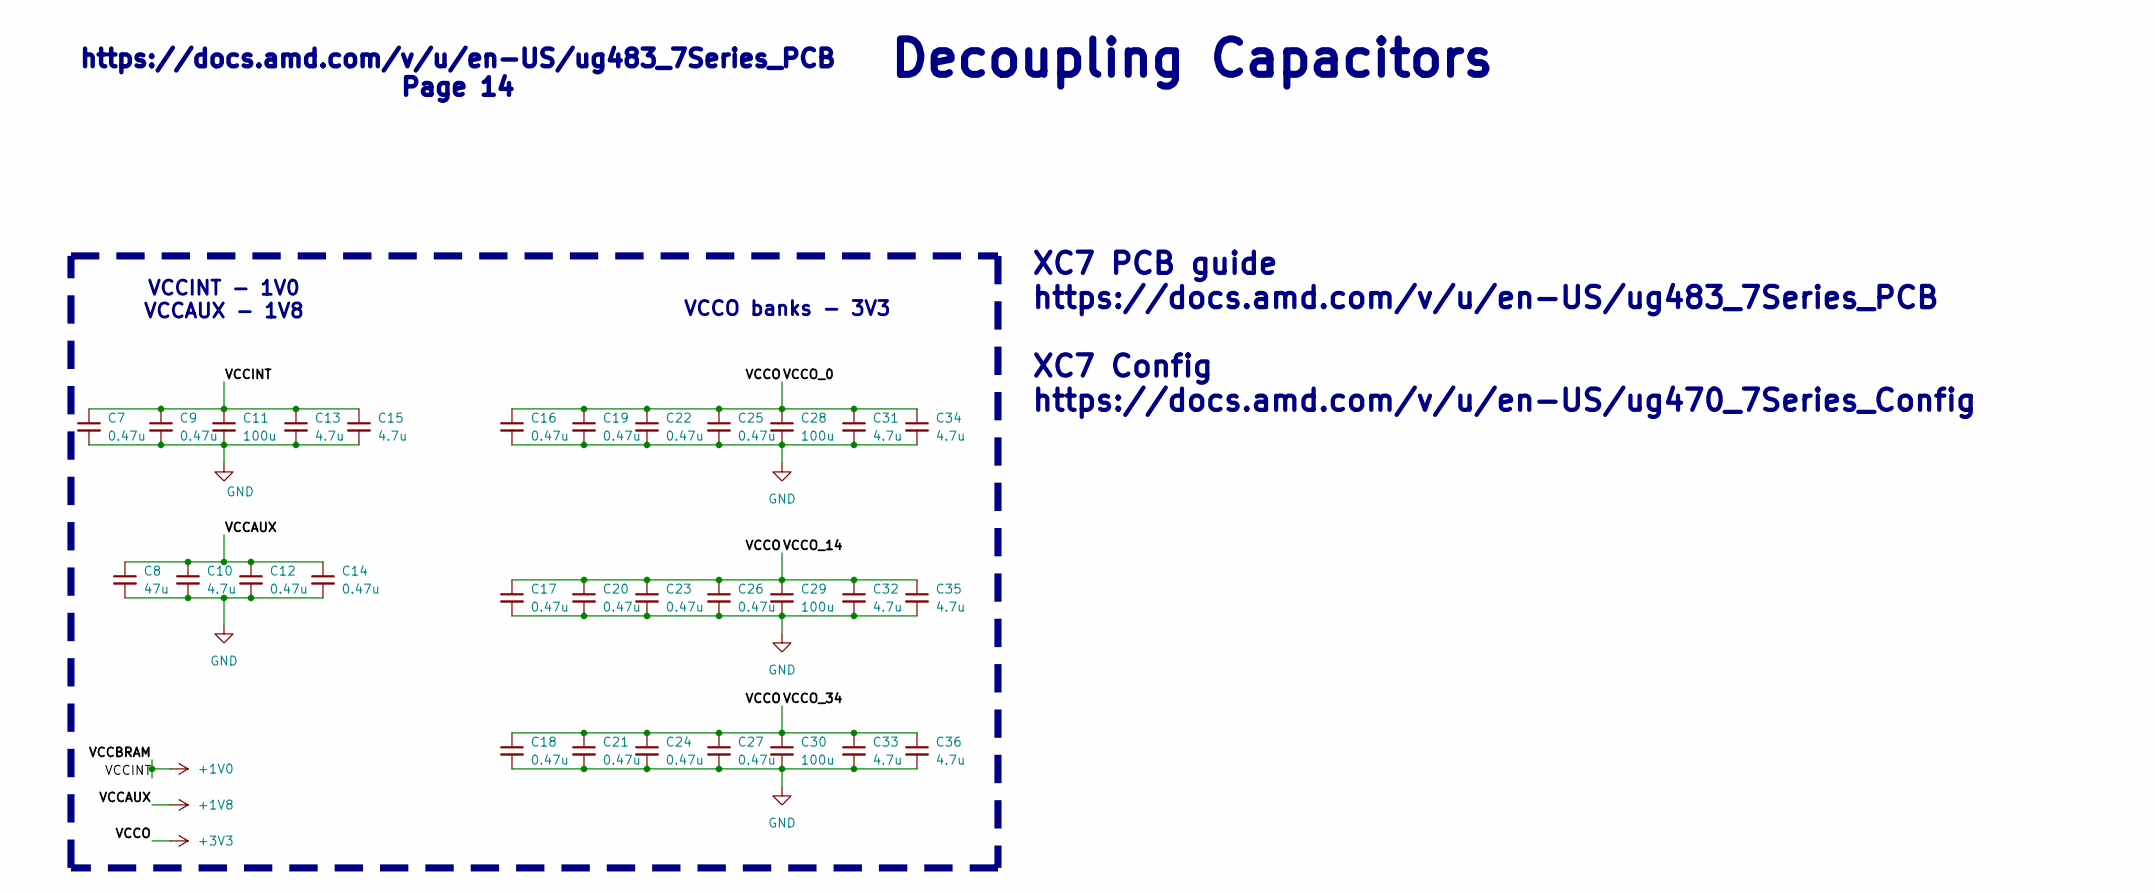
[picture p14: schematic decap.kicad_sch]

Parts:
C7, C9, C12, C14, C16, C17, C18, C19, C20, C21, C22, C23, C24, C25, C26, C27: 0.47u; C_0201_0603Metric
C8: 47u; C_0603_1608Metric
C10, C13, C15, C31, C32, C33, C34, C35, C36: 4.7u; C_0402_1005Metric
C11, C28, C29, C30: 100u; C_0603_1608Metric

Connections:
+1V0: C7.1, C9.1, C11.1, C13.1, C15.1; also elsewhere on the board
+1V8: C8.1, C10.1, C12.1, C14.1; also elsewhere on the board
+3V3: C16.1, C17.1, C18.1, C19.1, C20.1, C21.1, C22.1, C23.1, C24.1, C25.1, C26.1, C27.1, C28.1, C29.1, C30.1, C31.1, C32.1, C33.1, C34.1, C35.1, C36.1; also elsewhere on the board
GND: C7.2, C8.2, C9.2, C10.2, C11.2, C12.2, C13.2, C14.2, C15.2, C16.2, C17.2, C18.2, C19.2, C20.2, C21.2, C22.2, C23.2, C24.2, C25.2, C26.2, C27.2, C28.2, C29.2, C30.2, C31.2, C32.2, C33.2, C34.2, C35.2, C36.2; also elsewhere on the board

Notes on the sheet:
Decoupling Capacitors
XC7 PCB guide https://docs.amd.com/v/u/en-US/ug483_7Series_PCB XC7 Config https://docs.amd.com/v/u/en-US/ug470_7Series_Config
VCCO banks - 3V3
https://docs.amd.com/v/u/en-US/ug483_7Series_PCB Page 14
VCCINT - 1V0 VCCAUX - 1V8

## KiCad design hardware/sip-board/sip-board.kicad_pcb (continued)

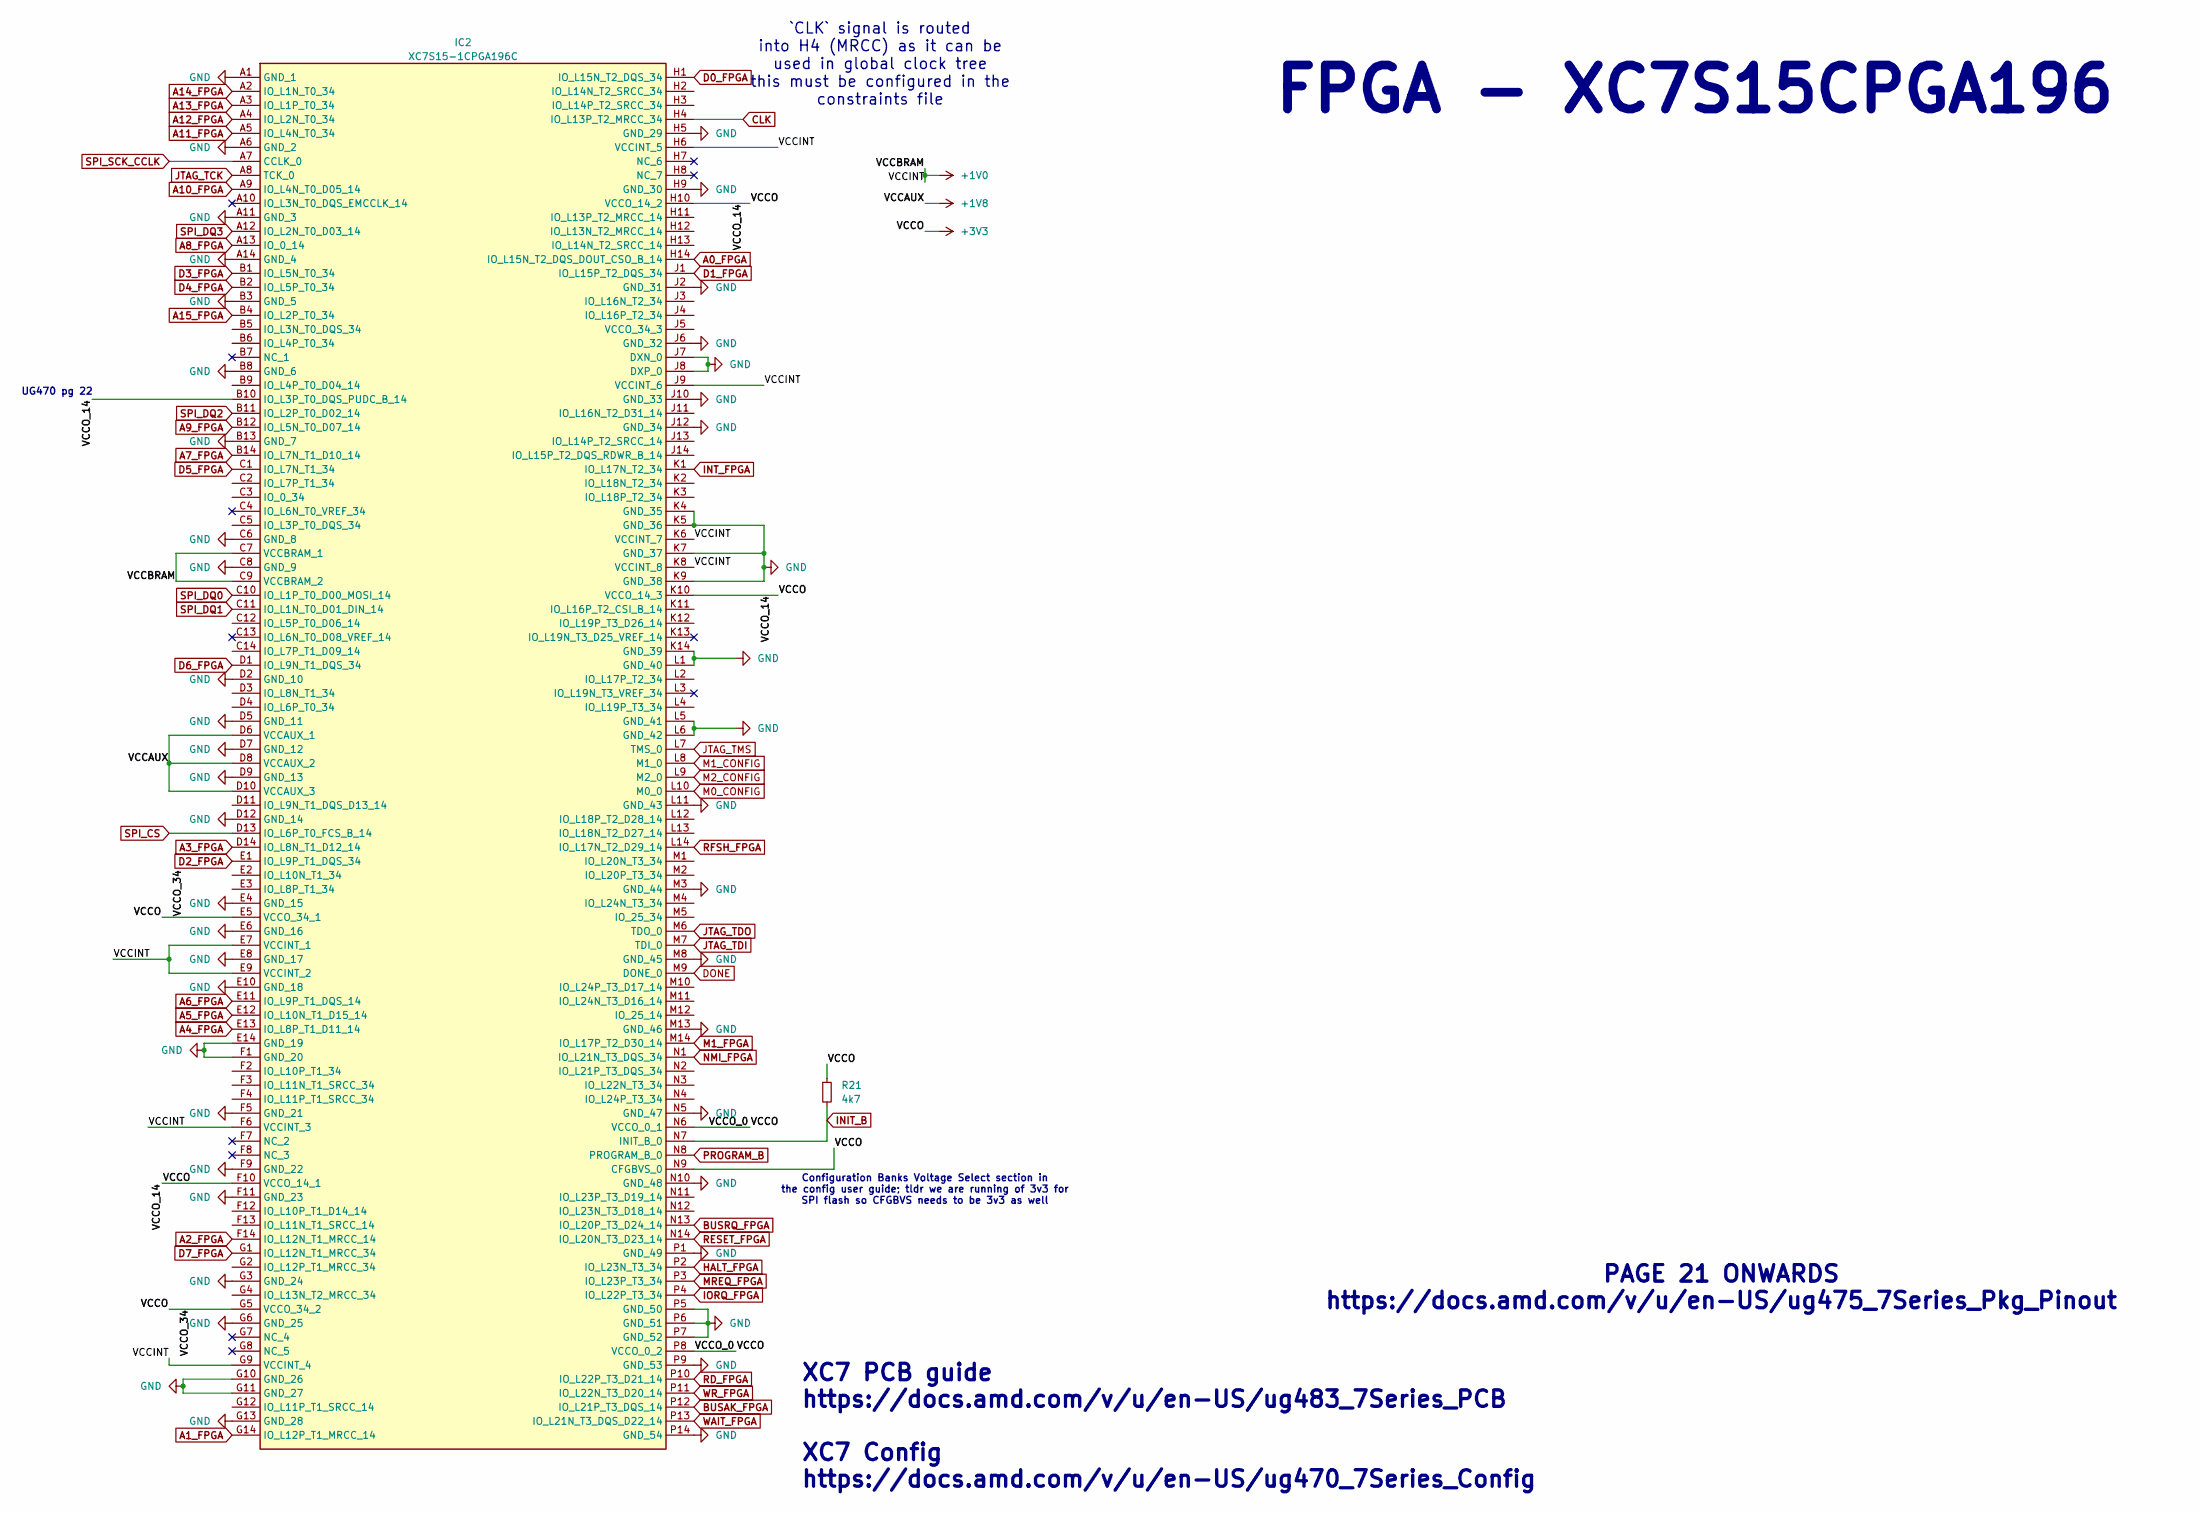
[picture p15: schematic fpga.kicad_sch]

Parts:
IC2: XC7S15-1CPGA196C; BGA196C50P14X14_800X800X110; Mouser Part Number 217-XC7S15-1CPGA196C
R21: 4k7; R_0201_0603Metric

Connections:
+1V0: IC2.C7 (VCCBRAM_1), IC2.C9 (VCCBRAM_2), IC2.E7 (VCCINT_1), IC2.E9 (VCCINT_2), IC2.F6 (VCCINT_3), IC2.G9 (VCCINT_4), IC2.H6 (VCCINT_5), IC2.J9 (VCCINT_6), IC2.K6 (VCCINT_7), IC2.K8 (VCCINT_8); also elsewhere on the board
+1V8: IC2.D6 (VCCAUX_1), IC2.D8 (VCCAUX_2), IC2.D10 (VCCAUX_3); also elsewhere on the board
+3V3: IC2.B10 (IO_L3P_T0_DQS_PUDC_B_14), IC2.E5 (VCCO_34_1), IC2.F10 (VCCO_14_1), IC2.G5 (VCCO_34_2), IC2.H10 (VCCO_14_2), IC2.K10 (VCCO_14_3), IC2.N6 (VCCO_0_1), IC2.N9 (CFGBVS_0), IC2.P8 (VCCO_0_2), R21.1; also elsewhere on the board
A0_FPGA: IC2.H14 (IO_L15N_T2_DQS_DOUT_CSO_B_14); also elsewhere on the board
A1_FPGA: IC2.G14 (IO_L12P_T1_MRCC_14); also elsewhere on the board
A2_FPGA: IC2.F14 (IO_L12N_T1_MRCC_14); also elsewhere on the board
A3_FPGA: IC2.D14 (IO_L8N_T1_D12_14); also elsewhere on the board
A4_FPGA: IC2.E13 (IO_L8P_T1_D11_14); also elsewhere on the board
A5_FPGA: IC2.E12 (IO_L10N_T1_D15_14); also elsewhere on the board
A6_FPGA: IC2.E11 (IO_L9P_T1_DQS_14); also elsewhere on the board
A7_FPGA: IC2.B14 (IO_L7N_T1_D10_14); also elsewhere on the board
A8_FPGA: IC2.A13 (IO_0_14); also elsewhere on the board
A9_FPGA: IC2.B12 (IO_L5N_T0_D07_14); also elsewhere on the board
A10_FPGA: IC2.A9 (IO_L4N_T0_D05_14); also elsewhere on the board
A11_FPGA: IC2.A5 (IO_L4N_T0_34); also elsewhere on the board
A12_FPGA: IC2.A4 (IO_L2N_T0_34); also elsewhere on the board
A13_FPGA: IC2.A3 (IO_L1P_T0_34); also elsewhere on the board
A14_FPGA: IC2.A2 (IO_L1N_T0_34); also elsewhere on the board
A15_FPGA: IC2.B4 (IO_L2P_T0_34); also elsewhere on the board
BUSAK_FPGA: IC2.P12 (IO_L21P_T3_DQS_14); also elsewhere on the board
BUSRQ_FPGA: IC2.N13 (IO_L20P_T3_D24_14); also elsewhere on the board
CLK: IC2.H4 (IO_L13P_T2_MRCC_34); also elsewhere on the board
D0_FPGA: IC2.H1 (IO_L15N_T2_DQS_34); also elsewhere on the board
D1_FPGA: IC2.J1 (IO_L15P_T2_DQS_34); also elsewhere on the board
D2_FPGA: IC2.E1 (IO_L9P_T1_DQS_34); also elsewhere on the board
D3_FPGA: IC2.B1 (IO_L5N_T0_34); also elsewhere on the board
D4_FPGA: IC2.B2 (IO_L5P_T0_34); also elsewhere on the board
D5_FPGA: IC2.C1 (IO_L7N_T1_34); also elsewhere on the board
D6_FPGA: IC2.D1 (IO_L9N_T1_DQS_34); also elsewhere on the board
D7_FPGA: IC2.G1 (IO_L12N_T1_MRCC_34); also elsewhere on the board
DONE: IC2.M9 (DONE_0); also elsewhere on the board
GND: IC2.A1 (GND_1), IC2.A6 (GND_2), IC2.A11 (GND_3), IC2.A14 (GND_4), IC2.B3 (GND_5), IC2.B8 (GND_6), IC2.B13 (GND_7), IC2.C6 (GND_8), IC2.C8 (GND_9), IC2.D2 (GND_10), IC2.D5 (GND_11), IC2.D7 (GND_12), IC2.D9 (GND_13), IC2.D12 (GND_14), IC2.E4 (GND_15), IC2.E6 (GND_16), IC2.E8 (GND_17), IC2.E10 (GND_18), IC2.E14 (GND_19), IC2.F1 (GND_20), IC2.F5 (GND_21), IC2.F9 (GND_22), IC2.F11 (GND_23), IC2.G3 (GND_24), IC2.G6 (GND_25), IC2.G10 (GND_26), IC2.G11 (GND_27), IC2.G13 (GND_28), IC2.H5 (GND_29), IC2.H9 (GND_30), IC2.J2 (GND_31), IC2.J6 (GND_32), IC2.J7 (DXN_0), IC2.J8 (DXP_0), IC2.J10 (GND_33), IC2.J12 (GND_34), IC2.K4 (GND_35), IC2.K5 (GND_36), IC2.K7 (GND_37), IC2.K9 (GND_38), IC2.K14 (GND_39), IC2.L1 (GND_40), IC2.L5 (GND_41), IC2.L6 (GND_42), IC2.L11 (GND_43), IC2.M3 (GND_44), IC2.M8 (GND_45), IC2.M13 (GND_46), IC2.N5 (GND_47), IC2.N10 (GND_48), IC2.P1 (GND_49), IC2.P5 (GND_50), IC2.P6 (GND_51), IC2.P7 (GND_52), IC2.P9 (GND_53), IC2.P14 (GND_54); also elsewhere on the board
HALT_FPGA: IC2.P2 (IO_L23N_T3_34); also elsewhere on the board
INIT_B: IC2.N7 (INIT_B_0), R21.2; also elsewhere on the board
INT_FPGA: IC2.K1 (IO_L17N_T2_34); also elsewhere on the board
IORQ_FPGA: IC2.P4 (IO_L22P_T3_34); also elsewhere on the board
JTAG_TCK: IC2.A8 (TCK_0); also elsewhere on the board
JTAG_TDI: IC2.M7 (TDI_0); also elsewhere on the board
JTAG_TDO: IC2.M6 (TDO_0); also elsewhere on the board
JTAG_TMS: IC2.L7 (TMS_0); also elsewhere on the board
M0_CONFIG: IC2.L10 (M0_0); also elsewhere on the board
M1_CONFIG: IC2.L8 (M1_0); also elsewhere on the board
M1_FPGA: IC2.M14 (IO_L17P_T2_D30_14); also elsewhere on the board
M2_CONFIG: IC2.L9 (M2_0); also elsewhere on the board
MREQ_FPGA: IC2.P3 (IO_L23P_T3_34); also elsewhere on the board
NMI_FPGA: IC2.N1 (IO_L21N_T3_DQS_34); also elsewhere on the board
PROGRAM_B: IC2.N8 (PROGRAM_B_0); also elsewhere on the board
RD_FPGA: IC2.P10 (IO_L22P_T3_D21_14); also elsewhere on the board
RESET_FPGA: IC2.N14 (IO_L20N_T3_D23_14); also elsewhere on the board
RFSH_FPGA: IC2.L14 (IO_L17N_T2_D29_14); also elsewhere on the board
SPI_CS: IC2.D13 (IO_L6P_T0_FCS_B_14); also elsewhere on the board
SPI_DQ0: IC2.C10 (IO_L1P_T0_D00_MOSI_14); also elsewhere on the board
SPI_DQ1: IC2.C11 (IO_L1N_T0_D01_DIN_14); also elsewhere on the board
SPI_DQ2: IC2.B11 (IO_L2P_T0_D02_14); also elsewhere on the board
SPI_DQ3: IC2.A12 (IO_L2N_T0_D03_14); also elsewhere on the board
SPI_SCK_CCLK: IC2.A7 (CCLK_0); also elsewhere on the board
WAIT_FPGA: IC2.P13 (IO_L21N_T3_DQS_D22_14); also elsewhere on the board
WR_FPGA: IC2.P11 (IO_L22N_T3_D20_14); also elsewhere on the board

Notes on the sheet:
UG470 pg 22
XC7 PCB guide https://docs.amd.com/v/u/en-US/ug483_7Series_PCB XC7 Config https://docs.amd.com/v/u/en-US/ug470_7Series_Config
Configuration Banks Voltage Select section in the config user guide; tldr we are running of 3v3 for SPI flash so CFGBVS needs to be 3v3 as well
PAGE 21 ONWARDS https://docs.amd.com/v/u/en-US/ug475_7Series_Pkg_Pinout
`CLK` signal is routed into H4 (MRCC) as it can be used in global clock tree this must be configured in the constraints file
FPGA - XC7S15CPGA196

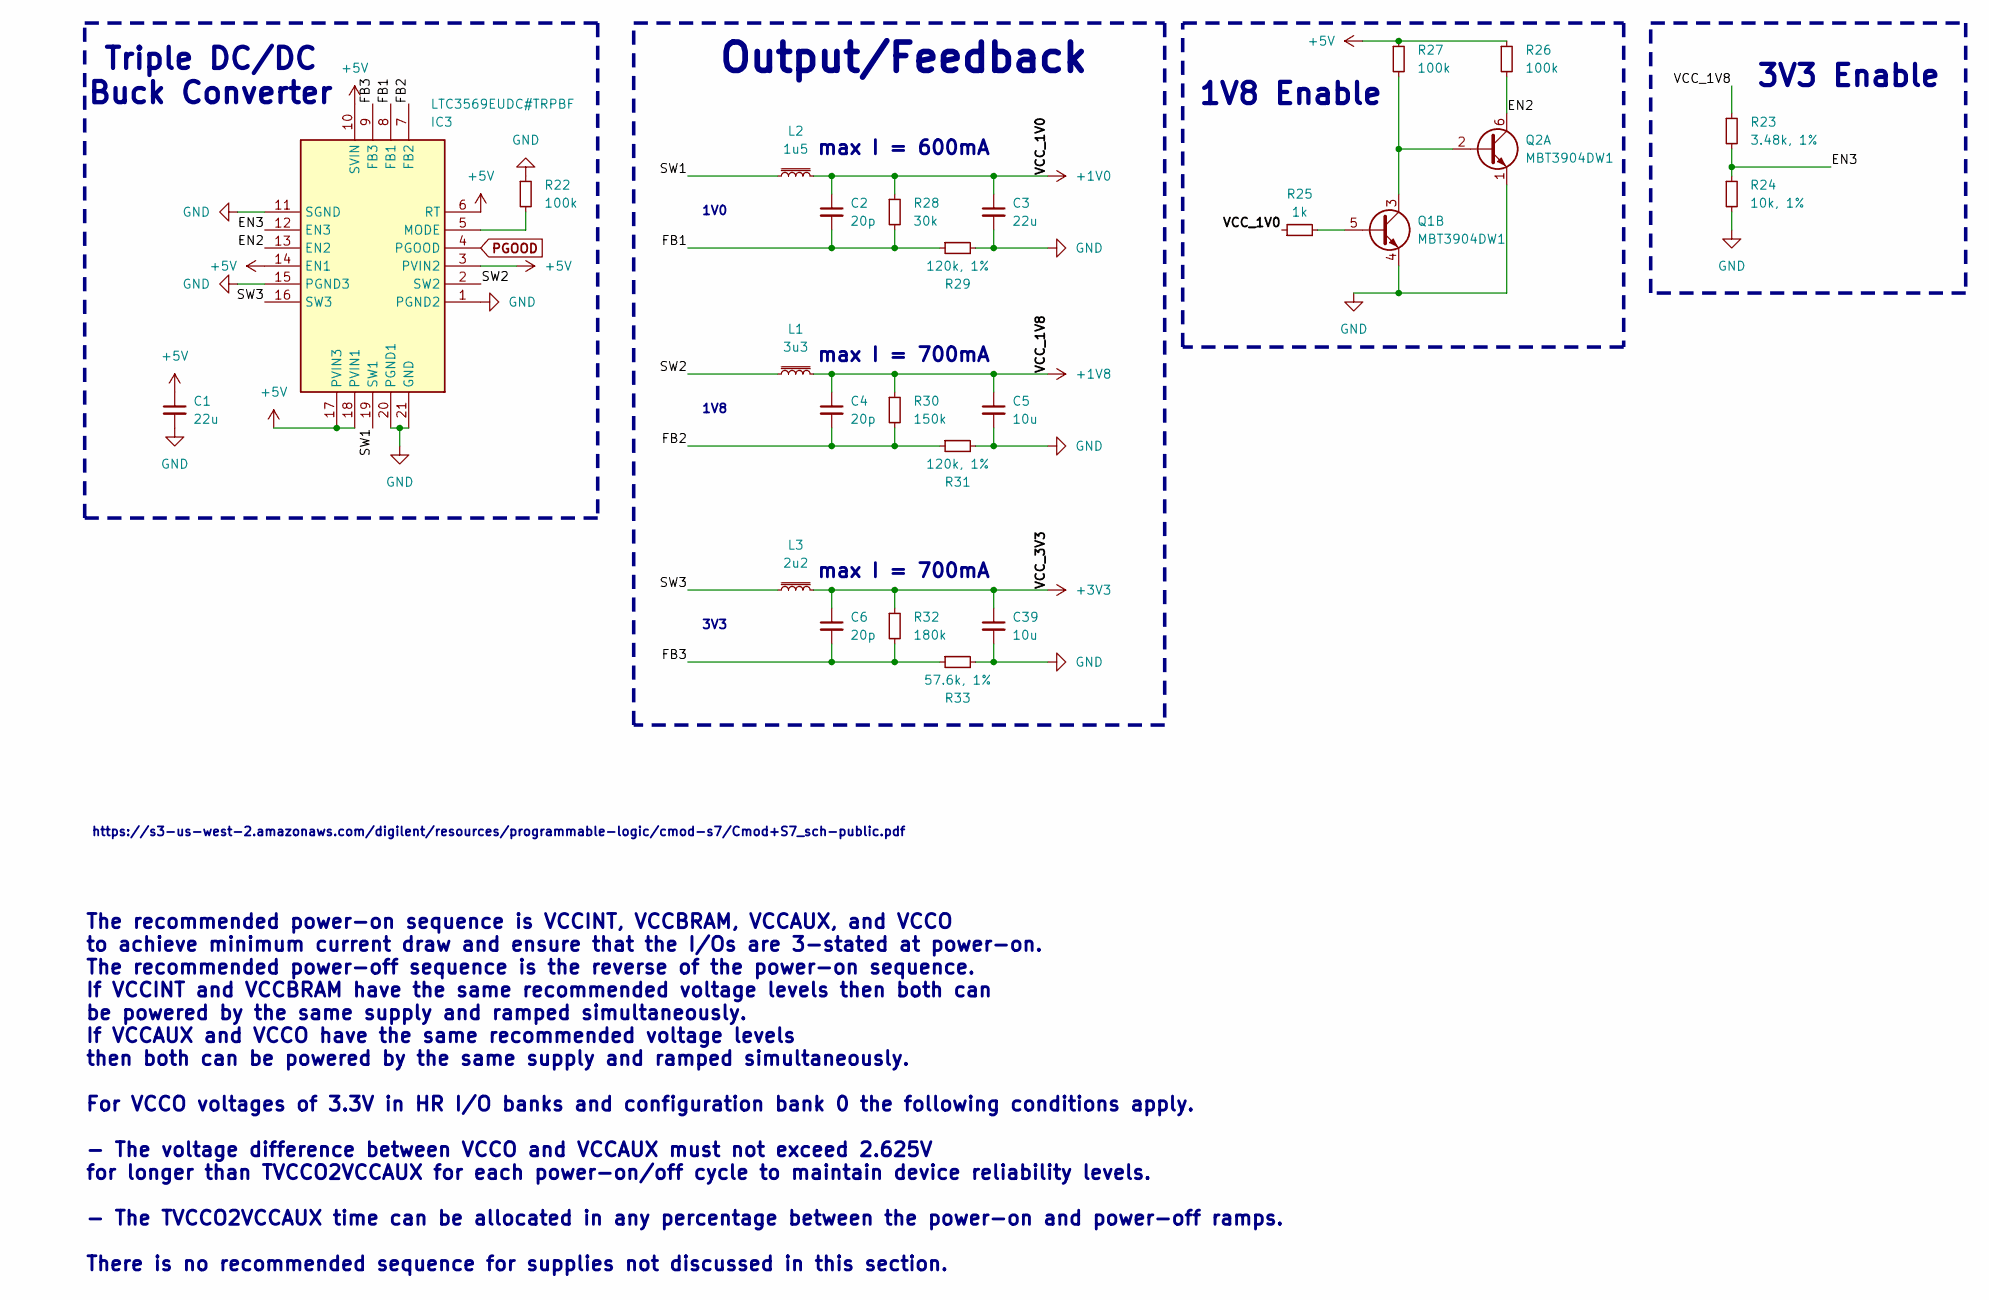
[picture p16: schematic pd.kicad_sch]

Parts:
C1, C3: 22u; C_0201_0603Metric
C2, C4, C6: 20p; C_0201_0603Metric
C5, C39: 10u; C_0201_0603Metric
IC3: LTC3569EUDC#TRPBF; QFN50P300X400X80-21N-D; Mouser Part Number 584-LTC3569EUDCTRPBF
L1: 3u3; L_0805_2012Metric; MPN BRC2012T3R3MD
L2: 1u5; L_0805_2012Metric; MPN SRN2012-1R5M
L3: 2u2; L_0805_2012Metric; MPN SRN2012-2R2M
Q1, Q2: MBT3904DW1; SOT-363_SC-70-6
R22, R26, R27: 100k; R_0201_0603Metric
R23: 3.48k, 1%; R_0201_0603Metric
R24: 10k, 1%; R_0201_0603Metric
R25: 1k; R_0201_0603Metric
R28: 30k; R_0201_0603Metric
R29, R31: 120k, 1%; R_0201_0603Metric
R30: 150k; R_0201_0603Metric
R32: 180k; R_0201_0603Metric
R33: 57.6k, 1%; R_0201_0603Metric

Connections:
+1V0: C2.1, C3.1, L2.2, R25.1, R28.1; also elsewhere on the board
+1V8: C4.1, C5.1, L1.2, R23.1, R30.1; also elsewhere on the board
+3V3: C6.1, C39.1, L3.2, R32.1; also elsewhere on the board
+5V: C1.1, IC3.3 (PVIN2), IC3.6 (RT), IC3.10 (SVIN), IC3.14 (EN1), IC3.17 (PVIN3), IC3.18 (PVIN1), R26.1, R27.1; also elsewhere on the board
/Voltage Regulators - 3V3, 1V8, 1V0/EN2: IC3.13 (EN2), Q2.6 (C1), R26.2
/Voltage Regulators - 3V3, 1V8, 1V0/EN3: IC3.12 (EN3), R23.2, R24.1
/Voltage Regulators - 3V3, 1V8, 1V0/FB1: C2.2, IC3.8 (FB1), R28.2, R29.1
/Voltage Regulators - 3V3, 1V8, 1V0/FB2: C4.2, IC3.7 (FB2), R30.2, R31.1
/Voltage Regulators - 3V3, 1V8, 1V0/FB3: C6.2, IC3.9 (FB3), R32.2, R33.1
/Voltage Regulators - 3V3, 1V8, 1V0/SW1: IC3.19 (SW1), L2.1
/Voltage Regulators - 3V3, 1V8, 1V0/SW2: IC3.2 (SW2), L1.1
/Voltage Regulators - 3V3, 1V8, 1V0/SW3: IC3.16 (SW3), L3.1
GND: C1.2, C3.2, C5.2, C39.2, IC3.1 (PGND2), IC3.11 (SGND), IC3.15 (PGND3), IC3.20 (PGND1), IC3.21 (GND), Q1.4 (E2), Q2.1 (E1), R22.1, R24.2, R29.2, R31.2, R33.2; also elsewhere on the board
unnamed: IC3.5 (MODE), R22.2
unnamed: Q1.5 (B2), R25.2
unnamed: Q1.3 (C2), Q2.2 (B1), R27.2
PGOOD: IC3.4 (PGOOD); also elsewhere on the board

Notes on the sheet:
3V3 Enable
max I = 700mA
3V3
Triple DC/DC Buck Converter
The recommended power-on sequence is VCCINT, VCCBRAM, VCCAUX, and VCCO to achieve minimum current draw and ensure that the I/Os are 3-stated at power-on. The recommended power-off sequence is the reverse of the power-on sequence. If VCCINT and VCCBRAM have the same recommended voltage levels then b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
1V0
max I = 600mA
1V8
https://s3-us-west-2.amazonaws.com/digilent/resources/programmable-logic/cmod-s7/Cmod+S7_sch-public.pdf
Output/Feedback
1V8 Enable

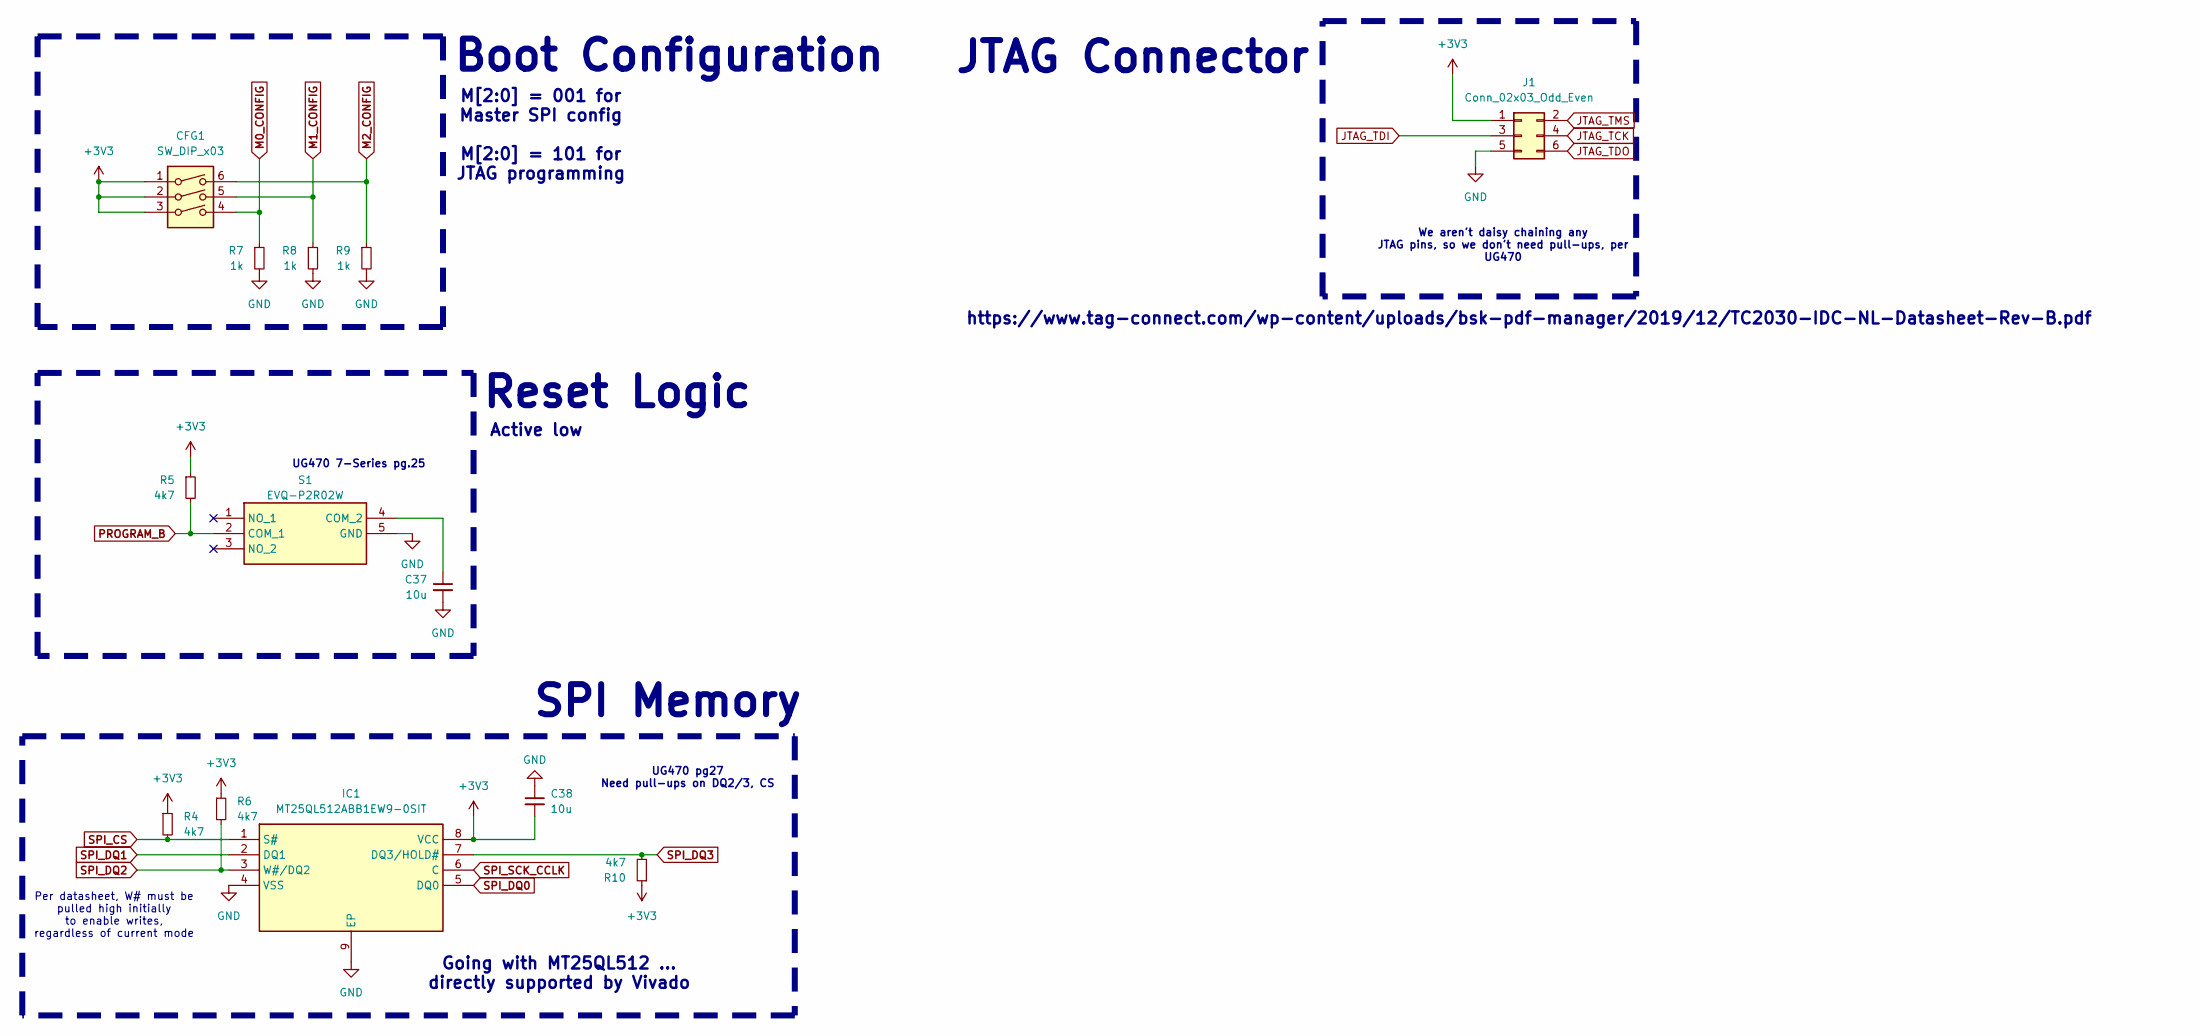
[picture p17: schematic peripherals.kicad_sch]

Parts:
C37, C38: 10u; C_0603_1608Metric
CFG1: SW_DIP_x03; WE-3-SPST-DIP
IC1: MT25QL512ABB1EW9-0SIT; Mouser Part Number 340-283908-TRAY
J1: Conn_02x03_Odd_Even; TAG_TC2030-IDC-NL
R4, R5, R6, R10: 4k7; R_0201_0603Metric
R7, R8, R9: 1k; R_0201_0603Metric
S1: EVQ-P2R02W; EVQP2R02W; Mouser Part Number 667-EVQ-P2R02W

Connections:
+3V3: C38.2, CFG1.1, CFG1.2, CFG1.3, IC1.8 (VCC), J1.1, R4.1, R5.1, R6.1, R10.1; also elsewhere on the board
GND: C37.2, C38.1, IC1.4 (VSS), IC1.9 (EP), J1.5, R7.2, R8.2, R9.2, S1.5 (GND); also elsewhere on the board
JTAG_TCK: J1.4; also elsewhere on the board
JTAG_TDI: J1.3; also elsewhere on the board
JTAG_TDO: J1.6; also elsewhere on the board
JTAG_TMS: J1.2; also elsewhere on the board
M0_CONFIG: CFG1.4, R7.1; also elsewhere on the board
M1_CONFIG: CFG1.5, R8.1; also elsewhere on the board
M2_CONFIG: CFG1.6, R9.1; also elsewhere on the board
unnamed: C37.1, S1.4 (COM_2)
PROGRAM_B: R5.2, S1.2 (COM_1); also elsewhere on the board
SPI_CS: IC1.1 (S#), R4.2; also elsewhere on the board
SPI_DQ0: IC1.5 (DQ0); also elsewhere on the board
SPI_DQ1: IC1.2 (DQ1); also elsewhere on the board
SPI_DQ2: IC1.3 (W#/DQ2), R6.2; also elsewhere on the board
SPI_DQ3: IC1.7 (DQ3/HOLD#), R10.2; also elsewhere on the board
SPI_SCK_CCLK: IC1.6 (C); also elsewhere on the board

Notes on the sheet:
Boot Configuration
https://www.tag-connect.com/wp-content/uploads/bsk-pdf-manager/2019/12/TC2030-IDC-NL-Datasheet-Rev-B.pdf
UG470 7-Series pg.25
M[2:0] = 001 for Master SPI config M[2:0] = 101 for JTAG programming
UG470 pg27 Need pull-ups on DQ2/3, CS
Reset Logic
JTAG Connector
Per datasheet, W# must be pulled high initially to enable writes, regardless of current mode
SPI Memory
Going with MT25QL512 ... directly supported by Vivado
Active low
We aren't daisy chaining any JTAG pins, so we don't need pull-ups, per UG470

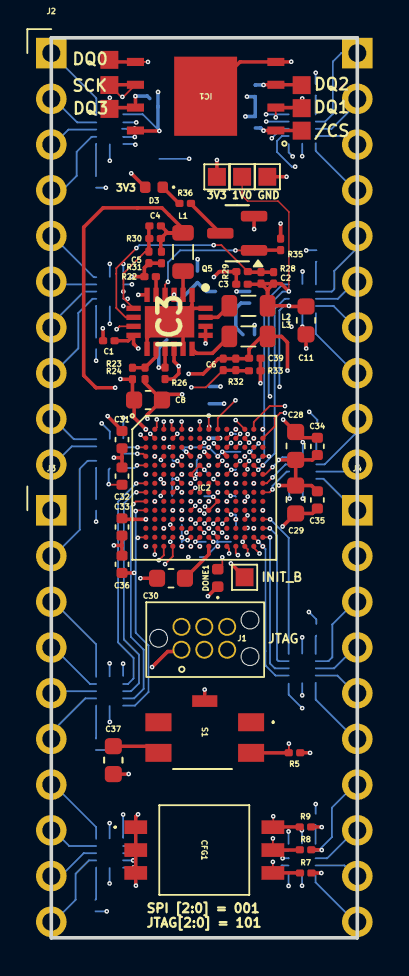
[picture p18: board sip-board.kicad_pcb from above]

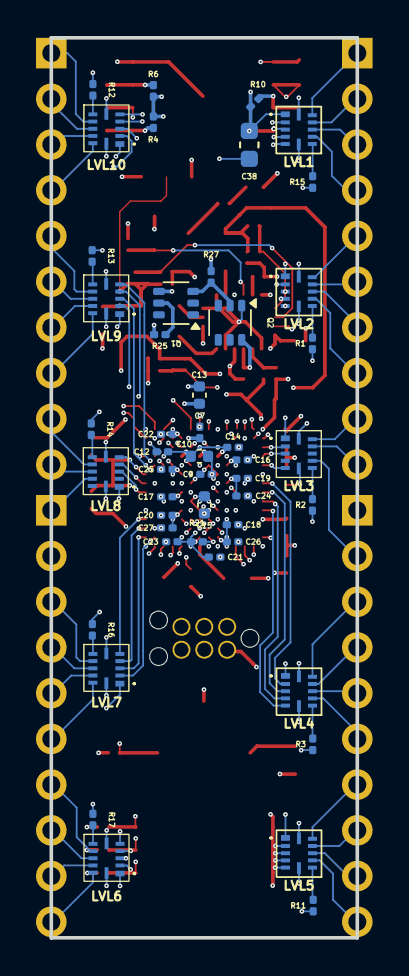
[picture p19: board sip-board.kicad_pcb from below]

Board: 10 copper layers, 17.0 x 50.0 mm, 109 parts (48 on the bottom side), 122 nets.

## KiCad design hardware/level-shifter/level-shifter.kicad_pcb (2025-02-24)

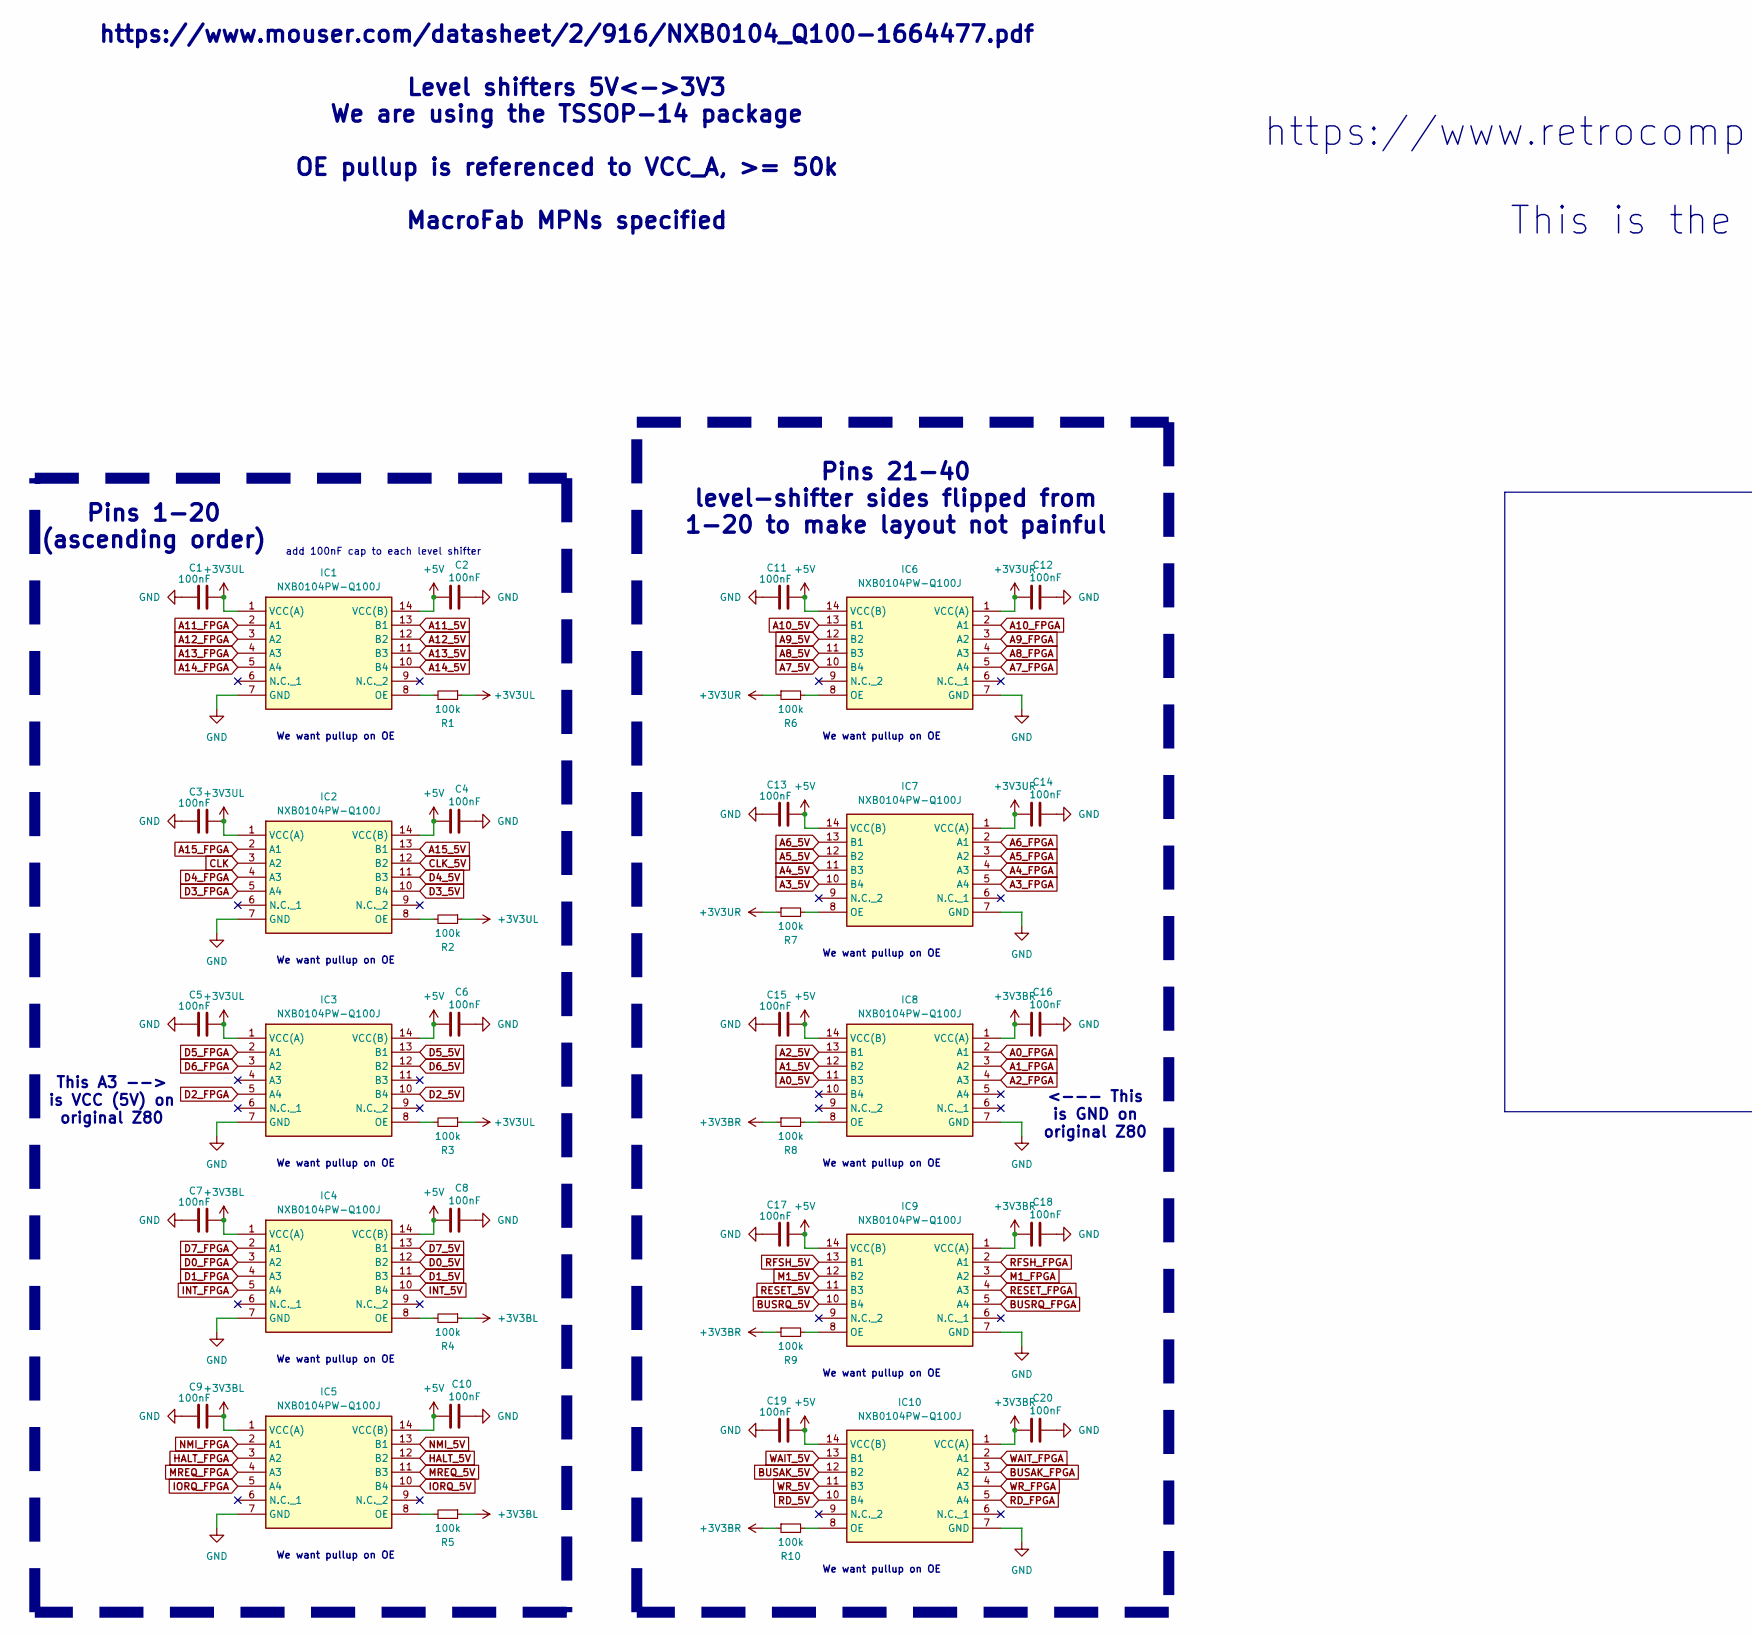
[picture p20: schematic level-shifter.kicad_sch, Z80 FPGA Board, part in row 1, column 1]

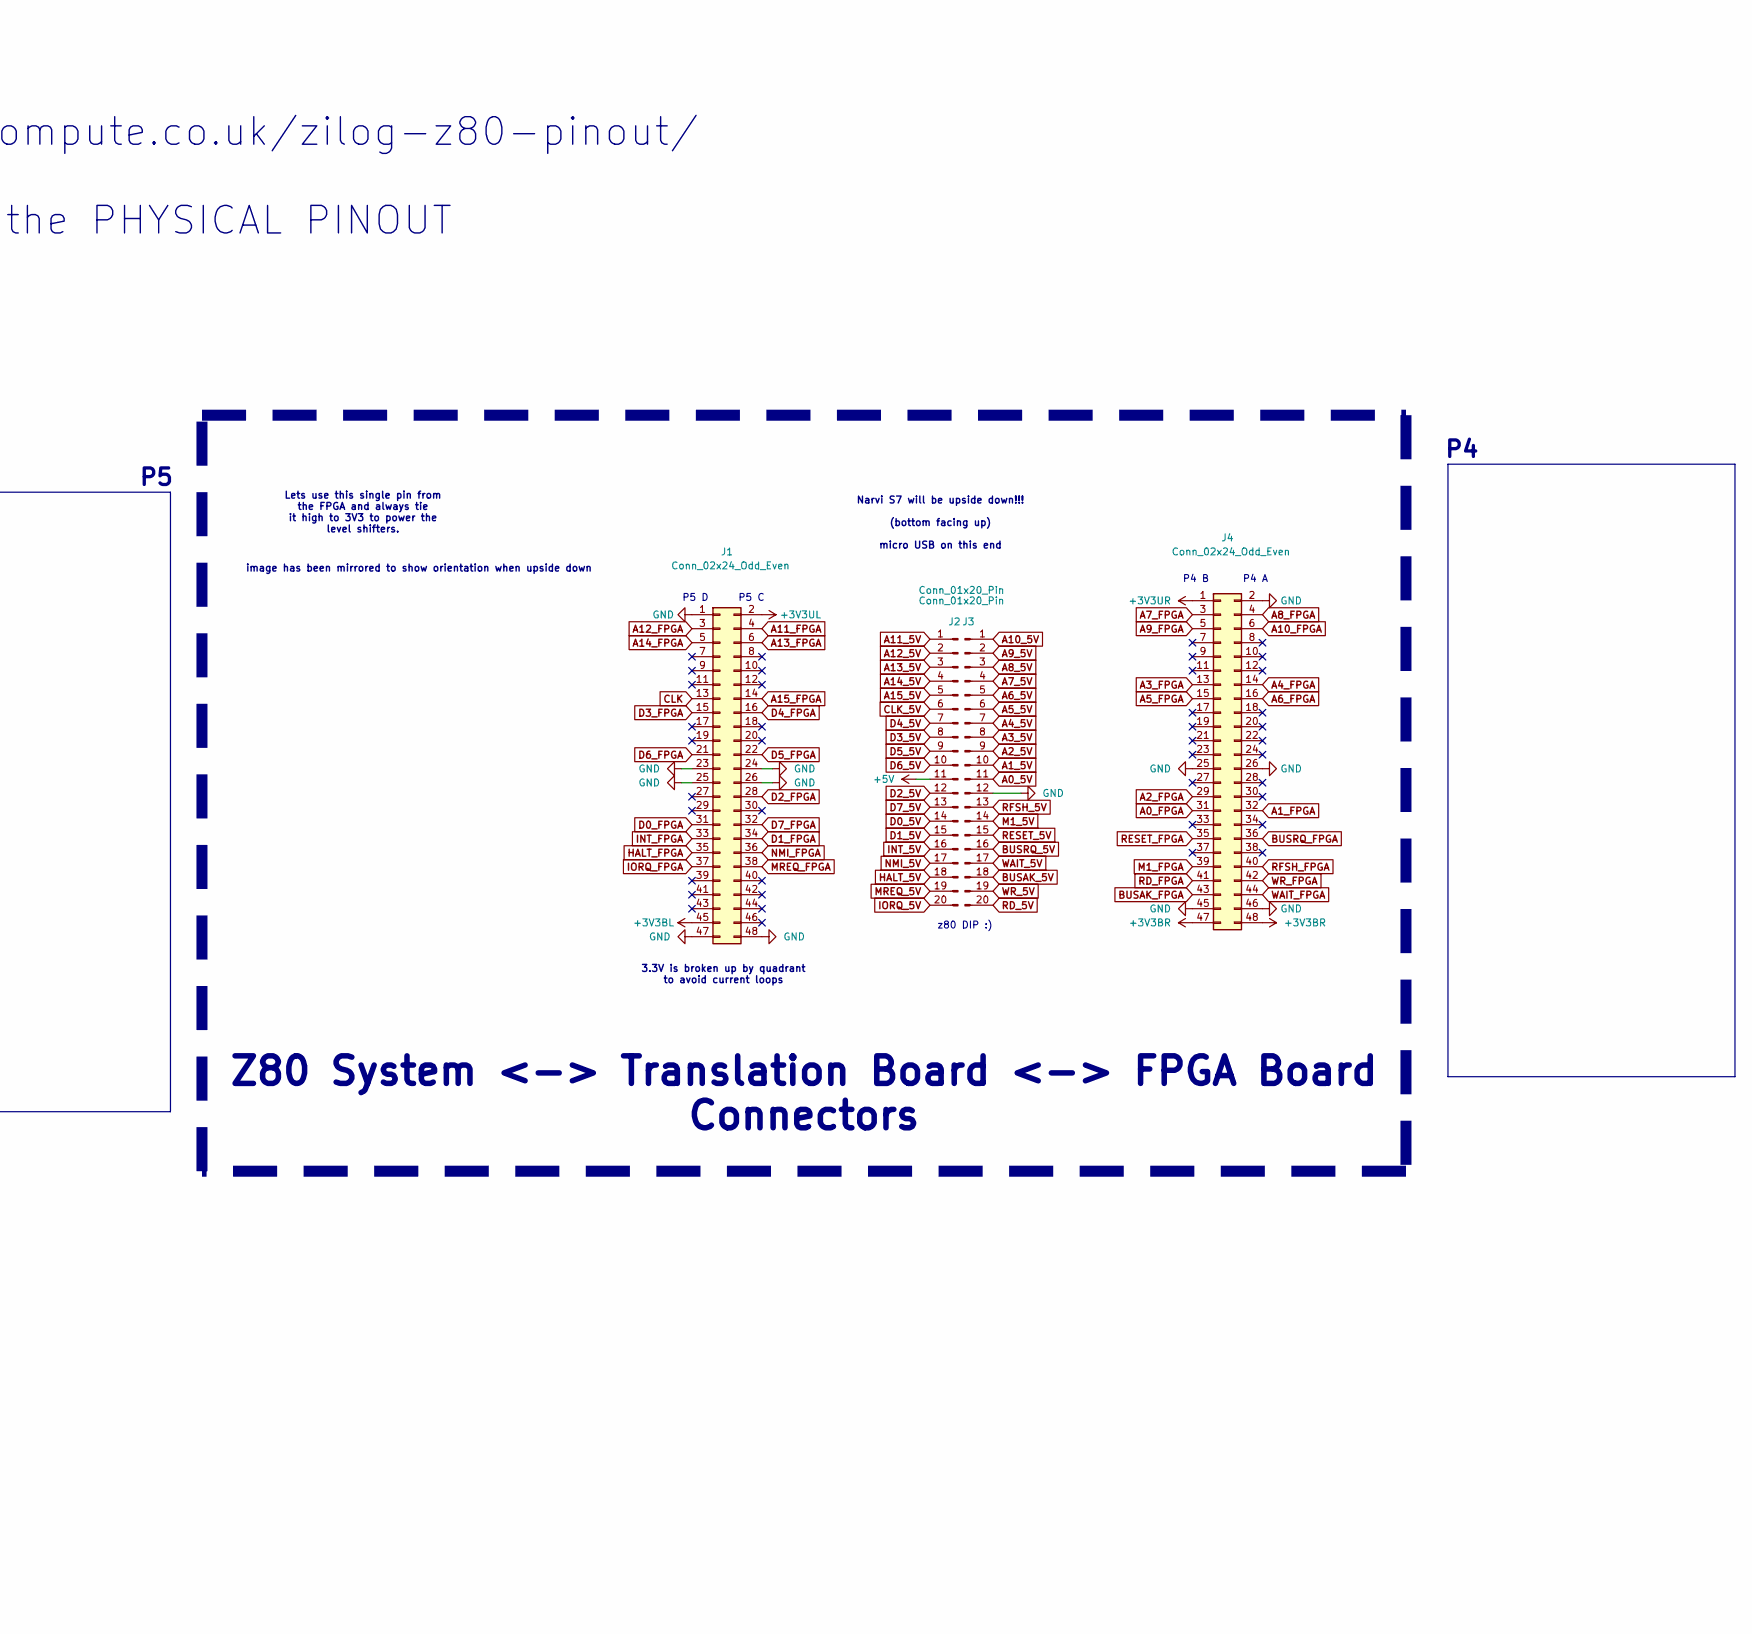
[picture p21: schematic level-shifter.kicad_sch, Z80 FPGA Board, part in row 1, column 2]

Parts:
C1, C2, C3, C4, C5, C6, C7, C8, C9, C10, C11, C12, C13, C14, C15, C16, C17, C18, C19, C20: 100nF; C_0805_2012Metric
IC1, IC2, IC3, IC4, IC5, IC6, IC7, IC8, IC9, IC10: NXB0104PW-Q100J; SOP65P640X110-14N; Mouser Part Number 771-NXB0104PW-Q100J
J1, J4: Conn_02x24_Odd_Even; PinHeader_2x24_P2.54mm_Vertical
J2, J3: Conn_01x20_Pin; PinHeader_1x20_P2.54mm_Vertical
R1, R2, R3, R4, R5, R6, R7, R8, R9, R10: 100k; R_0805_2012Metric; MPN ERJ-UP6D6202V

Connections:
+3V3BL: C7.2, C9.2, IC4.1 (VCC(A)), IC5.1 (VCC(A)), J1.45, R4.1, R5.1
+3V3BR: C16.1, C18.1, C20.1, IC8.1 (VCC(A)), IC9.1 (VCC(A)), IC10.1 (VCC(A)), J4.47, J4.48, R8.1, R9.1, R10.1
+3V3UL: C1.2, C3.2, C5.2, IC1.1 (VCC(A)), IC2.1 (VCC(A)), IC3.1 (VCC(A)), J1.2, R1.1, R2.1, R3.1
+3V3UR: C12.1, C14.1, IC6.1 (VCC(A)), IC7.1 (VCC(A)), J4.1, R6.1, R7.1
+5V: C2.1, C4.1, C6.1, C8.1, C10.1, C11.2, C13.2, C15.2, C17.2, C19.2, IC1.14 (VCC(B)), IC2.14 (VCC(B)), IC3.14 (VCC(B)), IC4.14 (VCC(B)), IC5.14 (VCC(B)), IC6.14 (VCC(B)), IC7.14 (VCC(B)), IC8.14 (VCC(B)), IC9.14 (VCC(B)), IC10.14 (VCC(B)), J2.11
A0_5V: IC8.11 (B3), J3.11
A0_FPGA: IC8.2 (A1), J4.31
A1_5V: IC8.12 (B2), J3.10
A1_FPGA: IC8.3 (A2), J4.32
A2_5V: IC8.13 (B1), J3.9
A2_FPGA: IC8.4 (A3), J4.29
A3_5V: IC7.10 (B4), J3.8
A3_FPGA: IC7.5 (A4), J4.13
A4_5V: IC7.11 (B3), J3.7
A4_FPGA: IC7.4 (A3), J4.14
A5_5V: IC7.12 (B2), J3.6
A5_FPGA: IC7.3 (A2), J4.15
A6_5V: IC7.13 (B1), J3.5
A6_FPGA: IC7.2 (A1), J4.16
A7_5V: IC6.10 (B4), J3.4
A7_FPGA: IC6.5 (A4), J4.3
A8_5V: IC6.11 (B3), J3.3
A8_FPGA: IC6.4 (A3), J4.4
A9_5V: IC6.12 (B2), J3.2
A9_FPGA: IC6.3 (A2), J4.5
A10_5V: IC6.13 (B1), J3.1
A10_FPGA: IC6.2 (A1), J4.6
A11_5V: IC1.13 (B1), J2.1
A11_FPGA: IC1.2 (A1), J1.4
A12_5V: IC1.12 (B2), J2.2
A12_FPGA: IC1.3 (A2), J1.3
A13_5V: IC1.11 (B3), J2.3
A13_FPGA: IC1.4 (A3), J1.6
A14_5V: IC1.10 (B4), J2.4
A14_FPGA: IC1.5 (A4), J1.5
A15_5V: IC2.13 (B1), J2.5
A15_FPGA: IC2.2 (A1), J1.14
BUSAK_5V: IC10.12 (B2), J3.18
BUSAK_FPGA: IC10.3 (A2), J4.43
BUSRQ_5V: IC9.10 (B4), J3.16
BUSRQ_FPGA: IC9.5 (A4), J4.36
CLK: IC2.3 (A2), J1.13
CLK_5V: IC2.12 (B2), J2.6
D0_5V: IC4.12 (B2), J2.14
D0_FPGA: IC4.3 (A2), J1.31
D1_5V: IC4.11 (B3), J2.15
D1_FPGA: IC4.4 (A3), J1.34
D2_5V: IC3.10 (B4), J2.12
D2_FPGA: IC3.5 (A4), J1.28
D3_5V: IC2.10 (B4), J2.8
D3_FPGA: IC2.5 (A4), J1.15
D4_5V: IC2.11 (B3), J2.7
D4_FPGA: IC2.4 (A3), J1.16
D5_5V: IC3.13 (B1), J2.9
D5_FPGA: IC3.2 (A1), J1.22
D6_5V: IC3.12 (B2), J2.10
D6_FPGA: IC3.3 (A2), J1.21
D7_5V: IC4.13 (B1), J2.13
D7_FPGA: IC4.2 (A1), J1.32
GND: C1.1, C2.2, C3.1, C4.2, C5.1, C6.2, C7.1, C8.2, C9.1, C10.2, C11.1, C12.2, C13.1, C14.2, C15.1, C16.2, C17.1, C18.2, C19.1, C20.2, IC1.7 (GND), IC2.7 (GND), IC3.7 (GND), IC4.7 (GND), IC5.7 (GND), IC6.7 (GND), IC7.7 (GND), IC8.7 (GND), IC9.7 (GND), IC10.7 (GND), J1.1, J1.23, J1.24, J1.25, J1.26, J1.47, J1.48, J3.12, J4.2, J4.25, J4.26, J4.45, J4.46
HALT_5V: IC5.12 (B2), J2.18
HALT_FPGA: IC5.3 (A2), J1.35
INT_5V: IC4.10 (B4), J2.16
INT_FPGA: IC4.5 (A4), J1.33
IORQ_5V: IC5.10 (B4), J2.20
IORQ_FPGA: IC5.5 (A4), J1.37
M1_5V: IC9.12 (B2), J3.14
M1_FPGA: IC9.3 (A2), J4.39
MREQ_5V: IC5.11 (B3), J2.19
MREQ_FPGA: IC5.4 (A3), J1.38
NMI_5V: IC5.13 (B1), J2.17
NMI_FPGA: IC5.2 (A1), J1.36
unnamed: IC1.8 (OE), R1.2
unnamed: IC2.8 (OE), R2.2
unnamed: IC3.8 (OE), R3.2
unnamed: IC4.8 (OE), R4.2
unnamed: IC5.8 (OE), R5.2
unnamed: IC6.8 (OE), R6.2
unnamed: IC7.8 (OE), R7.2
unnamed: IC8.8 (OE), R8.2
unnamed: IC9.8 (OE), R9.2
unnamed: IC10.8 (OE), R10.2
RD_5V: IC10.10 (B4), J3.20
RD_FPGA: IC10.5 (A4), J4.41
RESET_5V: IC9.11 (B3), J3.15
RESET_FPGA: IC9.4 (A3), J4.35
RFSH_5V: IC9.13 (B1), J3.13
RFSH_FPGA: IC9.2 (A1), J4.40
WAIT_5V: IC10.13 (B1), J3.17
WAIT_FPGA: IC10.2 (A1), J4.44
WR_5V: IC10.11 (B3), J3.19
WR_FPGA: IC10.4 (A3), J4.42

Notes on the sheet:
https://www.retrocompute.co.uk/zilog-z80-pinout/ This is the PHYSICAL PINOUT
We want pullup on OE
P4 A
P5 C
Z80 System <-> Translation Board <-> FPGA Board Connectors
P5 D
Pins 21-40 level-shifter sides flipped from 1-20 to make layout not painful
z80 DIP :)
3.3V is broken up by quadrant to avoid current loops
image has been mirrored to show orientation when upside down
Narvi S7 will be upside down!!! (bottom facing up) micro USB on this end
https://www.mouser.com/datasheet/2/916/NXB0104_Q100-1664477.pdf Level shifters 5V<->3V3 We are using the TSSOP-14 package OE pullup is referenced to VCC_A, >= 50k MacroFab MPNs specified
add 100nF cap to each level shifter
This A3 --> is VCC (5V) on original Z80
Lets use this single pin from the FPGA and always tie it high to 3V3 to power the level shifters.
<--- This is GND on original Z80
P4 B
Pins 1-20 (ascending order)



Board: 2 copper layers, 59.7 x 63.4 mm, 44 parts (2 on the bottom side), 92 nets.

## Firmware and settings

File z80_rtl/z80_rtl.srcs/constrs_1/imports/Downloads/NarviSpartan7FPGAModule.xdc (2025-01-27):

set_property CFGBVS VCCO [current_design]
set_property CONFIG_VOLTAGE 3.3 [current_design]

####################################################################################################################
#                                               CLOCK 100MHz                                                       #
####################################################################################################################
set_property PACKAGE_PIN D14 [get_ports CLK1]
set_property IOSTANDARD LVCMOS33 [get_ports CLK1]

####################################################################################################################
#                                               FT2232H Signals                                                    #
####################################################################################################################
set_property -dict { PACKAGE_PIN "L13"    IOSTANDARD LVCMOS33       SLEW FAST} [get_ports { RXD }]  ;               # IO_0_14                       Sch = FTDI-D0
set_property -dict { PACKAGE_PIN "N13"    IOSTANDARD LVCMOS33       SLEW FAST} [get_ports { TXD }]  ;               # IO_L6N_T0_D08_VREF_14         Sch = FTDI-D1
set_property -dict { PACKAGE_PIN "L17"    IOSTANDARD LVCMOS33       SLEW FAST} [get_ports { RTS }]  ;               # IO_L4P_T0_D04_14              Sch = FTDI-D2
set_property -dict { PACKAGE_PIN "L18"    IOSTANDARD LVCMOS33       SLEW FAST} [get_ports { CTS }]  ;               # IO_L4N_T0_D05_14              Sch = FTDI-D3
set_property -dict { PACKAGE_PIN "M17"    IOSTANDARD LVCMOS33       SLEW FAST} [get_ports { DATA[4] }]  ;               # IO_L7N_T1_D10_14              Sch = FTDI-D4
set_property -dict { PACKAGE_PIN "M18"    IOSTANDARD LVCMOS33       SLEW FAST} [get_ports { DATA[5] }]  ;               # IO_L8P_T1_D11_14              Sch = FTDI-D5
set_property -dict { PACKAGE_PIN "M16"    IOSTANDARD LVCMOS33       SLEW FAST} [get_ports { DATA[6] }]  ;               # IO_L7P_T1_D09_14              Sch = FTDI-D6
set_property -dict { PACKAGE_PIN "N18"    IOSTANDARD LVCMOS33       SLEW FAST} [get_ports { DATA[7] }]  ;               # IO_L8N_T1_D12_14              Sch = FTDI-D7

set_property -dict { PACKAGE_PIN "P17"    IOSTANDARD LVCMOS33       SLEW FAST} [get_ports { TXE_N }]    ;               # IO_L9P_T1_DQS_14              Sch = FTDI-TXE#
set_property -dict { PACKAGE_PIN "P18"    IOSTANDARD LVCMOS33       SLEW FAST} [get_ports { RXF_N }]    ;               # IO_L9N_T1_DQS_D13_14          Sch = FTDI-RXF#
set_property -dict { PACKAGE_PIN "T18"    IOSTANDARD LVCMOS33       SLEW FAST} [get_ports { WR_N  }]    ;               # IO_L10N_T1_D15_14             Sch = FTDI-WR#
set_property -dict { PACKAGE_PIN "R18"    IOSTANDARD LVCMOS33       SLEW FAST} [get_ports { RD_N  }]    ;               # IO_L10P_T1_D14_14             Sch = FTDI-RD#
set_property -dict { PACKAGE_PIN "R14"    IOSTANDARD LVCMOS33       SLEW FAST} [get_ports { CLKOUT}]    ;               # IO_L13P_T2_MRCC_14            Sch = FTDI-CLKOUT
set_property -dict { PACKAGE_PIN "R12"    IOSTANDARD LVCMOS33       SLEW FAST} [get_ports { OE_N  }]    ;               # IO_25_14                      Sch = FTDI-OE#
set_property -dict { PACKAGE_PIN "L16"    IOSTANDARD LVCMOS33       SLEW FAST} [get_ports { SIWUA }]    ;               # IO_L3N_T0_DQS_EMCCLK_14       Sch = FTDI-SIWUA
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

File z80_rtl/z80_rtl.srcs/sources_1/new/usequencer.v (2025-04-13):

`timescale 1ns / 1ps
`include "decode.v"
`include "fsm.v"

//////////////////////////////////////////////////////////////////////////////////
// Company:
// Engineer:
//
// Create Date: 01/24/2025 07:14:14 PM
// Design Name:
// Module Name: usequencer
// Project Name:
// Target Devices:
// Tool Versions:
// Description:
//
// Dependencies:
//
// Revision:
// Revision 0.01 - File Created
// Additional Comments:
//
//////////////////////////////////////////////////////////////////////////////////



module usequencer(
    input clk,
    input [7:0] flags,
    input [7:0] IR,

    // External control signals
    input ext_wait, // This is latched on opposite clock edge than the others I believe
    input ext_int,
    input ext_nmi,
    input ext_reset, //TODO: Figure out how we're handling resets
    input ext_busrq,

    output ext_m1,
    output ext_rfsh,
    output ext_busack,
    output ext_mreq,
    output ext_iorq,
    output ext_rd,
    output ext_wr,
    output reg ext_halt,

    output [49:0] m_signals,
    output [`TSIGNALS:0] t_signals,
    output jump_pc,

    output IX, IY
    );

    // External control signal latches
    reg wait_latch = 1; // wait is a keyword so I can't call it wait lol
    reg int = 1;
    reg nmi = 1;
    reg reset = 1;
    reg busrq = 1;

    reg mreq = 1;
    reg iorq = 1;
    reg rd = 1;
    reg wr = 1;

    // T-State signals
    reg [6:0] t_state = 0;
    wire [6:0] next_j_bits;
    wire [6:0] next_t_state;

    fsm t_cs(t_state, t_signals);
    
    //intermediate signal logic
    reg temp_mreq, temp_iorq, temp_rd, temp_wr;
    

    // Set signals to high impedence during bus grant
    assign ext_mreq = t_signals[`BUSACK] ? 1'bz : temp_mreq;
    assign ext_iorq = t_signals[`BUSACK] ? 1'bz : temp_iorq;
    assign ext_rd   = t_signals[`BUSACK] ? 1'bz : temp_rd;
    assign ext_wr   = t_signals[`BUSACK] ? 1'bz : temp_wr;

    
    // Decode logic

    wire [249:0] exec_sigs;
    wire [1:0] PLA_idx_w;
    wire [24:0] m_states;
    wire [2:0] max_m_cycles_w;
    wire [1:0] f_stall;
    wire [4:0] inst_next_m;
    wire next_IX_pref, next_IY_pref;
    wire no_int;
    wire cc_met;

    reg [2:0] m_cycle_ctr = 3'b0;
    reg [2:0] max_m_cycles = 3'b0;
    reg [1:0] PLA_idx = 2'b0;
    reg [1:0] IX_pref = 2'b0;
    reg [1:0] IY_pref = 2'b0;
    
    reg iff1 = 0;
    reg iff2 = 0;

    decode dec(IR, PLA_idx, IX_pref[1], IY_pref[1], exec_sigs, nmi, PLA_idx_w, m_states,
                     max_m_cycles_w, f_stall, next_IX_pref, next_IY_pref, no_int);

    upcoming_m_cycles umc(t_signals[`CS_SET], m_states, exec_sigs, m_cycle_ctr,
                      inst_next_m, m_signals);


    assign ext_m1 = !t_signals[`M1_HIGH];
    assign ext_rfsh = t_signals[`BUSACK] ? 1'bz : !t_signals[`RFSH];
    assign ext_busack = !t_signals[`BUSACK];

    assign IX = IX_pref[1];
    assign IY = IY_pref[1];

    wire [1:0] stall;
    assign stall = f_stall | {m_signals[`STALL_2], m_signals[`STALL_1]};

    assign next_j_bits[6:3] = t_signals[`J6:`J3];

    assign next_j_bits[2] = t_signals[`J2] | (t_signals[`COND1] & stall[1]);
    assign next_j_bits[1] = t_signals[`J1] | (t_signals[`COND1] &
                                              (stall[0] | (cc_met & m_signals[`CONDSTALL])));
    assign next_j_bits[0] = t_signals[`J0] | (t_signals[`COND0] & wait_latch);

    wire [6:0] next_m;

    next_m_cycle_logic next_m_logic(int, nmi, busrq, inst_next_m, m_cycle_ctr,
                                    max_m_cycles, iff1, no_int, next_m);

    assign next_t_state = t_signals[`LAST_T] ? next_m : next_j_bits;


    wire [2:0] condition;


    // Chooses from y, y-4, NZ, and Z based on EXEC signals
    assign condition = m_signals[`MUX_EXEC_COND_1] ?
        (m_signals[`MUX_EXEC_COND_0] ? 3'b001 : 3'b000) :
        (m_signals[`MUX_EXEC_COND_0] ? (IR[5:3]-4) : IR[5:3]);

    flag_logic fl(flags, condition, cc_met);

    
    assign jump_pc = m_signals[`PC_CONDLD] && cc_met && t_signals[`INC_PC];

    //reg temp_mreq, temp_iorq, temp_rd, temp_wr;

    always @(*) begin
        if (t_signals[`MREQ_R] && ~clk) begin
            temp_mreq = 0;
        end else if (t_signals[`MREQ_S_FE] && ~clk) begin
            temp_mreq = 1;
        end else begin
            temp_mreq = mreq;
        end
    
        if (t_signals[`IORQ_R] && ~clk) begin
            temp_iorq = 0;
        end else if (t_signals[`IORQ_S_FE] && ~clk) begin
            temp_iorq = 1;
        end else begin
            temp_iorq = iorq;
        end
    
        if (t_signals[`RD_R] && ~clk) begin
            temp_rd = 0;
        end else if (t_signals[`RD_S_FE] && ~clk) begin
            temp_rd = 1;
        end else begin
            temp_rd = rd;
        end
    
        if (t_signals[`WR_R] && ~clk) begin
            temp_wr = 0;
        end else if (t_signals[`WR_S_FE] && ~clk) begin
            temp_wr = 1;
        end else begin
            temp_wr = wr;
        end
    end
    

    always @(posedge clk) begin
        // Update input latches
        int <= ext_int;
        nmi <= ext_nmi;
        reset <= ext_reset;
        busrq <= ext_busrq;

        #20 t_state <= next_t_state;

        // Update output latches only if not waiting
        if(!(t_signals[`COND0] && !wait_latch)) begin
            if(t_signals[`MREQ_S_RE])
                mreq <= 1;

            if(t_signals[`IORQ_S_RE])
                iorq <= 1;

            if(t_signals[`RD_S_RE])
                rd <= 1;

            if(t_signals[`RD_R_RE])
                rd <= 0;

            if(t_signals[`WR_S_RE])
                wr <= 1;

            if(t_signals[`WR_R_RE])
                wr <= 0;
        end
        
        if(t_signals[`MREQ_R])
            mreq <= 0;
        else if(t_signals[`MREQ_S_FE])
            mreq <= 1;

        if(t_signals[`IORQ_R])
            iorq <= 0;
        else if(t_signals[`IORQ_S_FE])
            iorq <= 1;

        if(t_signals[`RD_R])
            rd <= 0;
        else if(t_signals[`RD_S_FE])
            rd <= 1;

        if(t_signals[`WR_R])
            wr <= 0;
        else if(t_signals[`WR_S_FE])
            wr <= 1;
        

        if(t_signals[`CS_SET]) begin
            m_cycle_ctr <= 0;
            max_m_cycles <= max_m_cycles_w;
            IX_pref[0] <= next_IX_pref;
            IY_pref[0] <= next_IY_pref;

        end

        if(t_signals[`EXEC])
            m_cycle_ctr <= m_cycle_ctr + 1;

        if((m_cycle_ctr == max_m_cycles) && t_signals[`LAST_T]) begin
            PLA_idx <= 0;
            IX_pref <= IX_pref << 1;
            IY_pref <= IY_pref << 1;
        end

        if(t_signals[`LAST_T]) begin
            PLA_idx <= PLA_idx_w;
        end

        if(m_signals[`DEC_MCTR_CC] & !cc_met)
            max_m_cycles = max_m_cycles - 1;

        if(m_signals[`DEC2_MCTR_CC] & !cc_met)
            max_m_cycles = max_m_cycles - 2;

        if(m_signals[`INT_FF_RESET]) begin
            iff1 <= 0;
            iff2 <= 0;
        end
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

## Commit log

2024-09-12 setup kicad proj
    [hardware.kicad_pcb, hardware.kicad_sch]
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2024-09-23 moving over to wires, looks like I'll need to write a ALU mux module
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2024-09-23 Fixed up latches for real this time
    [ALU.v]
2024-09-24 Fixed up Half Carry CC, latches came back :(
    [ALU.v]
2024-09-24 Finished? Doesn't follow undocumented exactly and needs optimizations
    [ALU.v]
2024-09-24 Added ALU testbench and fixed a bug
    [ALU.v]
2024-10-07 restart hardware proj
    [hardware.kicad_sch]
2024-10-07 add hardware stuff for symbol/footprint of level shifter
    [hardware.kicad_sch]
2024-10-09 update level shifter adapter board schematic
    [hardware.kicad_sch]
2024-10-09 first general schematic/layout pushed. need to look into some stuff
    [freerouting.dsn, hardware.kicad_pcb, hardware.kicad_sch]
2024-10-09 fix pcb planes
    [hardware.kicad_pcb]
2024-10-12 add XC7S15 8x8 BGA footprint and symbol to kicad project
    [hardware.kicad_pcb]
2024-10-12 reorganize some pcb stuff, begin kicad for sip board
    [freerouting.dsn, hardware.kicad_sch, level-shifter.kicad_pcb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]
2024-10-13 Renamed params to match opcodes and fixed up some undocumented behav
    [ALU.v]
2024-10-14 wire up LDOs
    [sip-board.kicad_sch]
2024-10-14 boot config and spi eeprom
    [sip-board.kicad_sch]
2024-10-14 jtag connector, decoupling caps, level shifters on schematic
    [sip-board.kicad_pcb, sip-board.kicad_sch]
2024-10-14 begin layout for sip
    we will need to use pcbway
    [sip-board.kicad_pcb]
2024-10-15 fix some connections, layout
    [sip-board.kicad_pcb, sip-board.kicad_sch]
2024-10-16 update via settings
    [sip-board.kicad_pcb]
2024-10-16 redid part of the board
    [sip-board.kicad_pcb, sip-board.kicad_sch]
2024-10-16 castellated hole edges, add 3d model
    [sip-board.kicad_pcb]
2024-10-16 pinout labels
    [sip-board.kicad_pcb]
2024-10-17 some cleanup
    [sip-board.kicad_pcb]
2024-10-18 follow marco stackup
    [sip-board.kicad_pcb]
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2024-10-18 actually added the tests in this one and added A and F swapping (EX)
    [ALU.v]
2024-10-19 wip layout, part placement
    [sip-board.kicad_pcb, sip-board.kicad_sch]
2024-10-20 More ALU tests and fixed a couple bugs
    [ALU.v]
2024-10-26 End to end testing on ALU performed, couple of bug fixes
    [ALU.v]
2024-11-04 Changed Register File .v. Also fixed and ran synthesis and implementation for current .v code
    Got rid of tristate buffers on regfile outputs.
    Fixed some more issues with implimentation (mainly some multiply-accessed warnings with the internal regfile bus)
    Kept tristates in front of register decoder and as input to the internal regbus. These can be chagned later but I think the regbus tristate buffer should stay since we will want REG_MUX_OUT to be separated from internal bus most of the time.
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2024-12-06 Finish draft 1(.5?) of SiP board. Needs to be looked at again and probably redone.
    [XC7S25-2CSGA225I.stp, sip-board.kicad_pcb, sip-board.kicad_sch]
2025-01-14 add new spi chip supported by vivado
    [sip-board.kicad_pcb, sip-board.kicad_sch]
2025-01-14 3d model for fpga, part placement done(?)
    Look into Xilinx programming adapters still. We do not have lots of space to work with.
    [sip-board.kicad_pcb, sip-board.kicad_sch]
2025-01-15 update to use relative paths
    [MT25QL512ABB1EW9-0SIT.stp, sip-board.kicad_sch]
2025-01-15 fix the paths (again)
    [sip-board.kicad_pcb, sip-board.kicad_sch]
2025-01-16 add new parts: button, jtag connector
    [EVQ-P2R02W.stp, TC2030-IDC-NL.step, sip-board.kicad_pcb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]
2025-01-16 placement done, new dip switch
    need to start picking parts and routing
    [416131160803.stp, connectors.kicad_sch, decap.kicad_sch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]
2025-01-16 stop routing need to change schematic (again)
    [sip-board.kicad_pcb]
2025-01-16 raahhhhh my eyeballs hurt
    [LTC3569EUDC#TRPBF.stp, pd.kicad_sch, peripherals.kicad_sch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]
2025-01-18 non-gpio routing done for "v3" (really like v6)
    [sip-board.kicad_pcb]
2025-01-18 remove all but 3v3 LED
    not enough voltage/current from the other 2 power rails to light up an LED
    [peripherals.kicad_sch, sip-board.kicad_pcb, sip-board.kicad_sch]
2025-01-21 Some fixes I don't remember
    [ALU.v]
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2025-01-28 level shifter redo
    [bom.csv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]
2025-01-28 remove old files from level shifter proj, add MPN for macrofab possible assembly
    [bom.csv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]
2025-01-28 use marco USB header and filtering, add MPNs, via stitching for power planes
    [level-shifter.kicad_pcb, level-shifter.kicad_sch]
2025-01-30 remove python testing stuff from branch; april uart/ila will be used instead
2025-01-30 WE REDOIN PCB
    [decap.kicad_sch, pd.kicad_sch, peripherals.kicad_sch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]
2025-01-30 Funny slicer and ALU no longer has AF registers
    [ALU.v]
2025-01-30 redo layout of sip (again), changed switching reg to be on surface, need to route, need to add 2 more layers for 5V plane
    [pinout_external.kicad_sch, sip-board.kicad_pcb]
2025-01-30 work on layout (im sad)
    [sip-board.kicad_pcb]
2025-01-31 add gnd stitching vias. buried.
    [sip-board.kicad_pcb]
2025-02-02 start of devhat redo
    remove usb stuff because the devboard supplies 3.3v
    pinout of devboard was wackier than previously thought
    [level-shifter.kicad_pcb, level-shifter.kicad_sch]
2025-02-02 devhat redo "done"
    NO PEEKING AT THE BOARD UNTIL THE REVEAL!!!
    [level-shifter.kicad_pcb, level-shifter.kicad_sch]
2025-02-02 sending off for review
    [level-shifter.kicad_pcb]
2025-02-03 added decoupling caps to level shifters
    [level-shifter.kicad_sch]
2025-02-04 updated DRC to match MacroFab
    [sip-board.kicad_pcb]
2025-02-04 Off for review (again)
    [level-shifter.kicad_pcb, level-shifter.kicad_sch]
2025-02-05 prep for redo switching regulator sip
    [pd.kicad_sch, sip-board.kicad_pcb]
2025-02-06 wip vreg
    [pd.kicad_sch, sip-board.kicad_pcb]
2025-02-08 sip vreg redo, connect level shifters to outside pins
    [pinout_external.kicad_sch, sip-board.kicad_pcb, sip-board.kicad_sch]
2025-02-11 routed to level shifters, need to address DRC
    [fpga.kicad_sch, sip-board.kicad_pcb]
2025-02-16 Made progress on wiring up the datapath
    Changes need to be made because there is some hairbrained stuff going on
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2025-02-26 Fix bug with external control signals set on rising edge
    [decode.v, usequencer.v]
2025-02-26 Fix syntax error in IFF handling (I committed too soon. :P)
    [usequencer.v]
2025-02-26 Fix NMI to be active low in decode
    [decode.v]
2025-03-09 quick adjustment for DRC
    [sip-board.kicad_pcb]
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2025-03-19 move silkscreen around
    [sip-board.kicad_pcb]
2025-03-31 setup kicad for breakout board
    [computer_breakout.kicad_pcb, computer_breakout.kicad_sch]
2025-04-07 untested code that might not work
    [usequencer.v]
